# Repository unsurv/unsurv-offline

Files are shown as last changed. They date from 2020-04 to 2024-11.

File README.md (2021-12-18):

# unsurv-offline

Currently available on [crowdsupply](https://www.crowdsupply.com/unsurv-technologies/unsurv-offline)

This project is part of the unsurv framework to fight privacy invasive technologies in the offline world. unsurv-offline logs your encounters with surveillance cameras and creates a daily report for you via NFC to review in the unsurv-companion Android app.

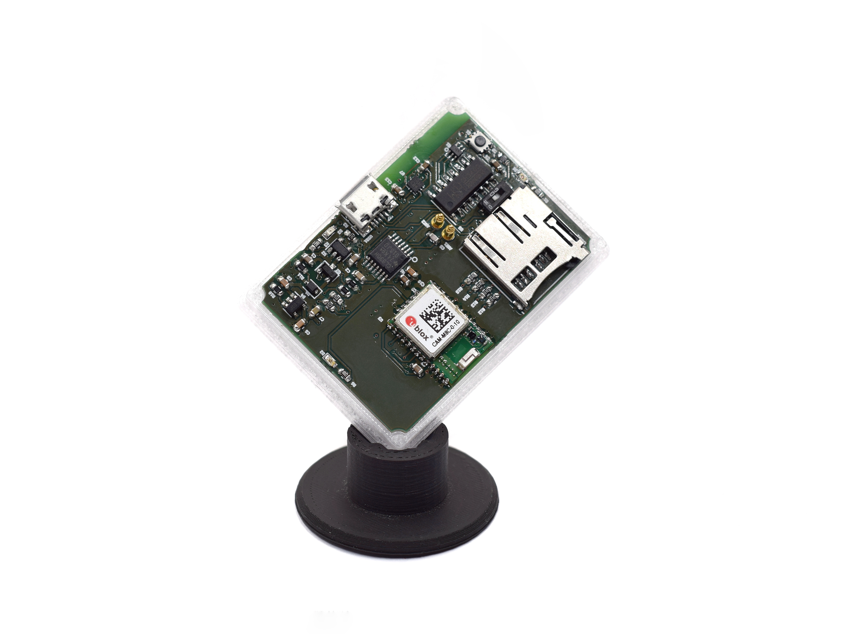
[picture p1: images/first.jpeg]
main PCB unsurv-offline


Demo: https://vimeo.com/497241039

This device can easily be adapted to different use cases via the Arduino IDE. Arduino library + board integration are planned.

List of features

- ESP32 D4
- ublox M8C GNSS receiver
- RF430CL330H NFC 
- BMA400 accelerometer
- SD card reader
- MCP73831 single cell LiPo charging
- CH340 USB to Serial

Software:
- [unsurv-offline](https://github.com/unsurv/unsurv-offline/tree/master/software/unsurv-offline)
- [other examples](https://github.com/unsurv/unsurv-offline/tree/master/software/examples) (tap to log location, location logging + step counting)

Hardware:
- [PCB design](https://github.com/unsurv/unsurv-offline/tree/master/unsurv_offline_pcb/main) (KiCad files)
- [case design](https://github.com/unsurv/unsurv-offline/tree/master/case) (FreeCAD + STL files)

Special thanks to:

- SparkFun for maintaining the [ublox library](https://github.com/sparkfun/SparkFun_Ublox_Arduino_Library)
- [awong1900](https://github.com/awong1900/RF430CL330H_Shield) for his work on the RF430
- [kriswiner](https://github.com/kriswiner/BMA400) for his BMA400 library

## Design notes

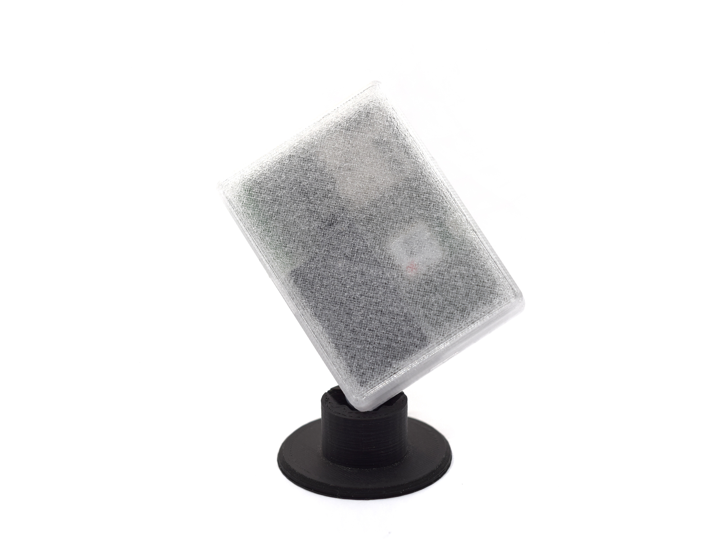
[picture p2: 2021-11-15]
images/third.jpeg

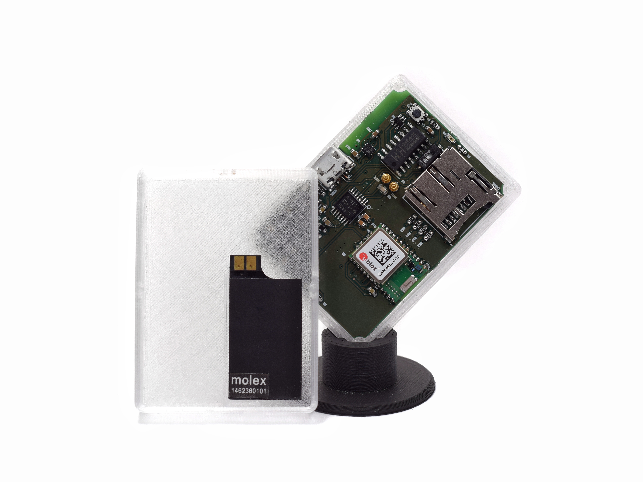
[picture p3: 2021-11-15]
images/pledge_kit.jpeg

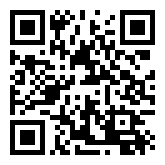
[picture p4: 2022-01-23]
images/GitHub_QR.png

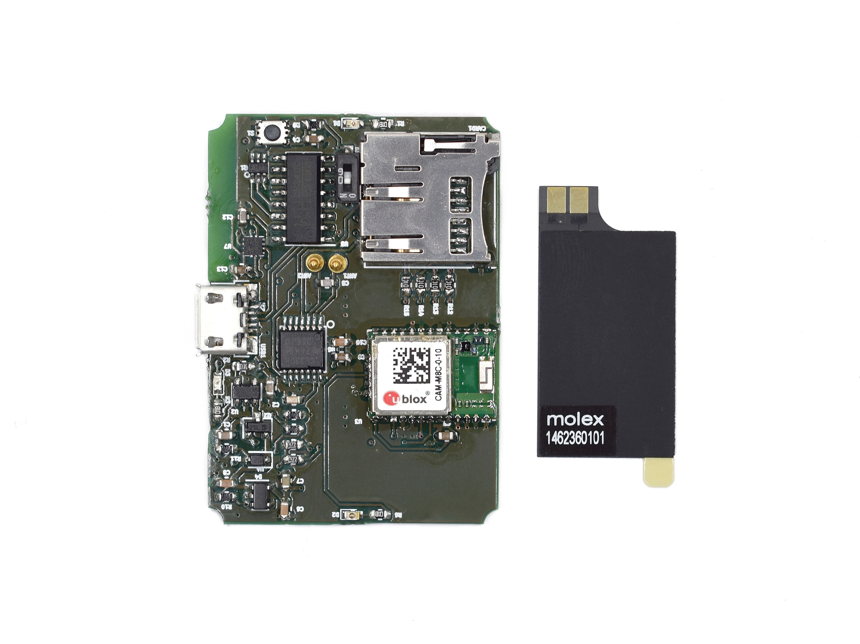
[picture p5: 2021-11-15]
images/pledge_pcb.jpeg

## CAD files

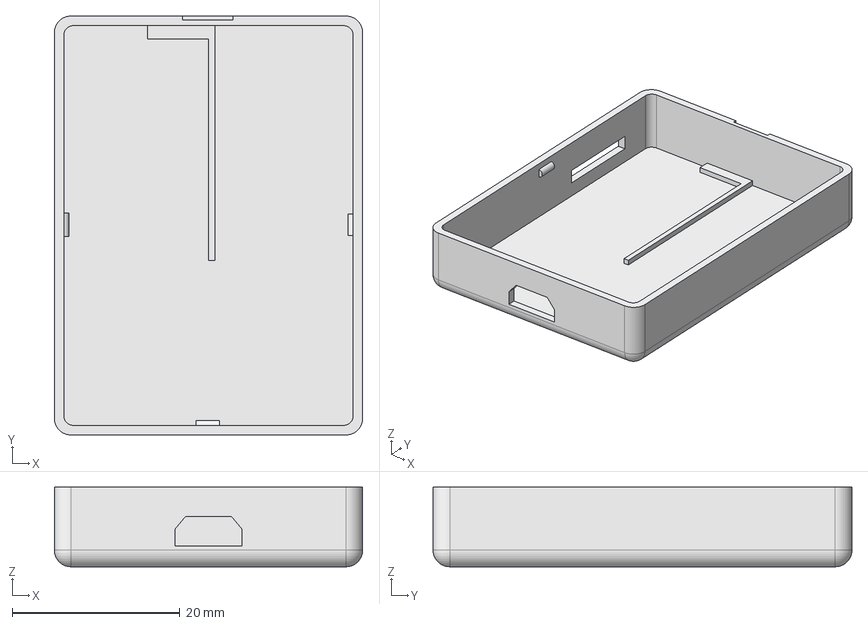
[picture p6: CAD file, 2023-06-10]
case/d4_case_top .FCStd
36.8 x 50.0 x 9.50 mm

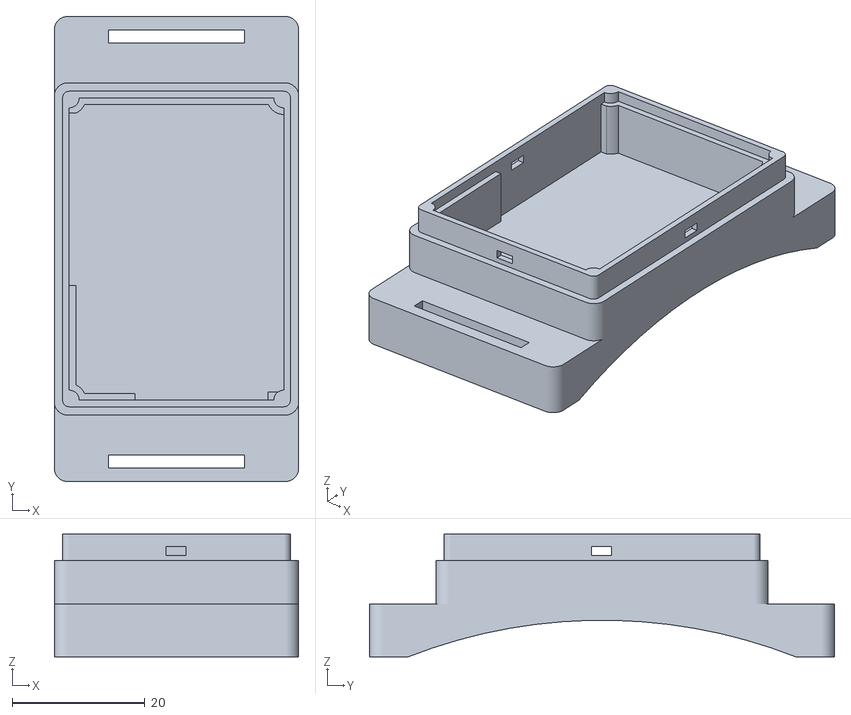
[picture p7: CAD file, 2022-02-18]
case/special/d4_case_bottom_collar_mount-Body.stl
36.8 x 70.0 x 18.5

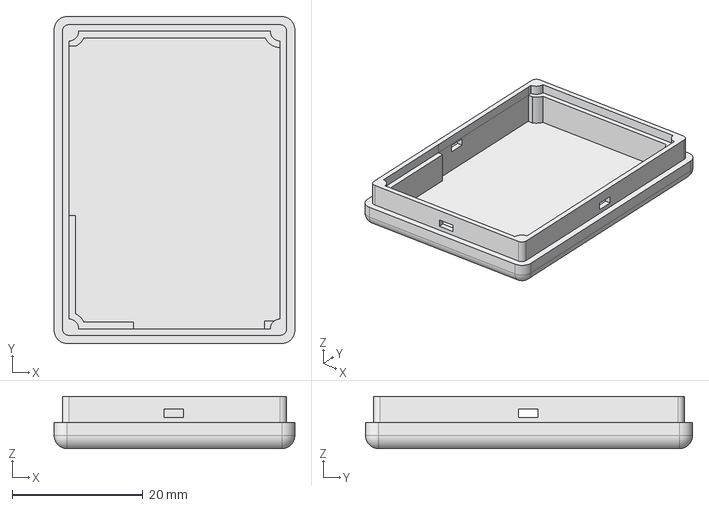
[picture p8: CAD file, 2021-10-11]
case/d4_case_bottom.FCStd
36.8 x 50.0 x 8.00 mm

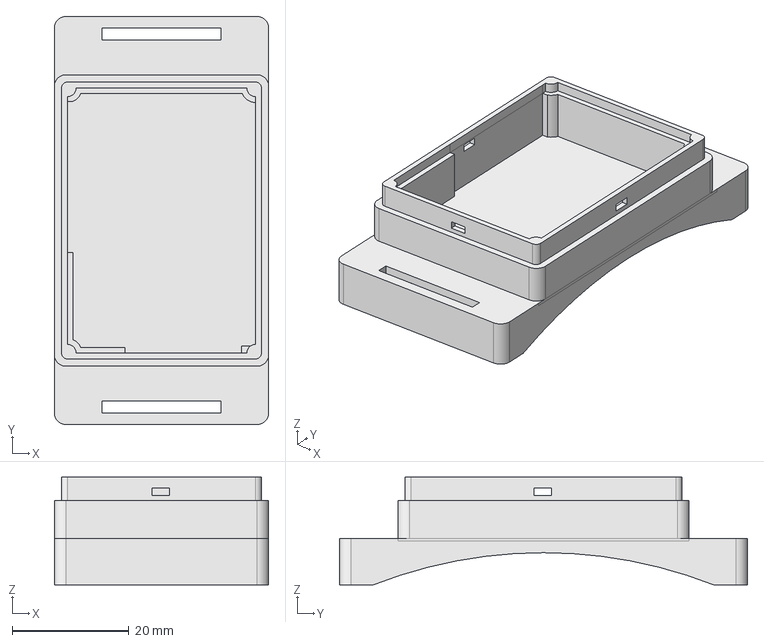
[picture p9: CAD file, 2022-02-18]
case/special/d4_case_bottom_collar_mount.FCStd
36.8 x 70.0 x 18.5 mm

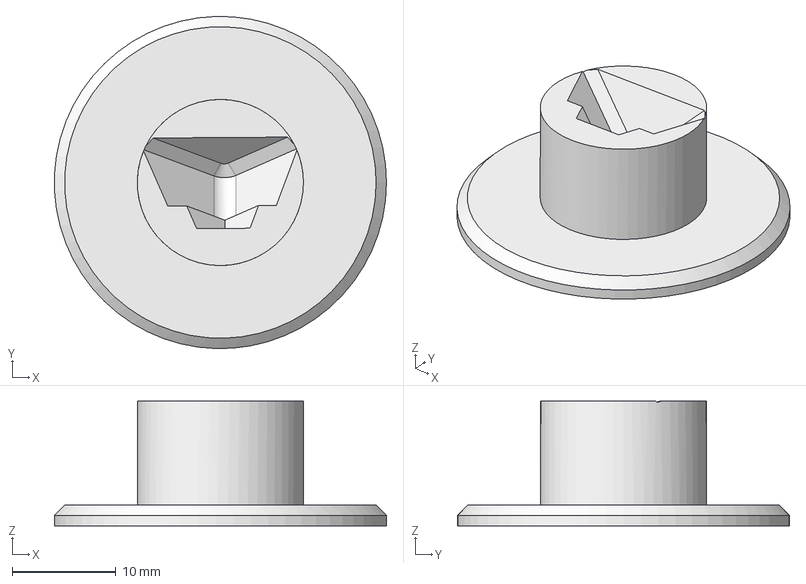
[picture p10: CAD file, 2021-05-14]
case/stand.FCStd
32.0 x 32.0 x 12.0 mm

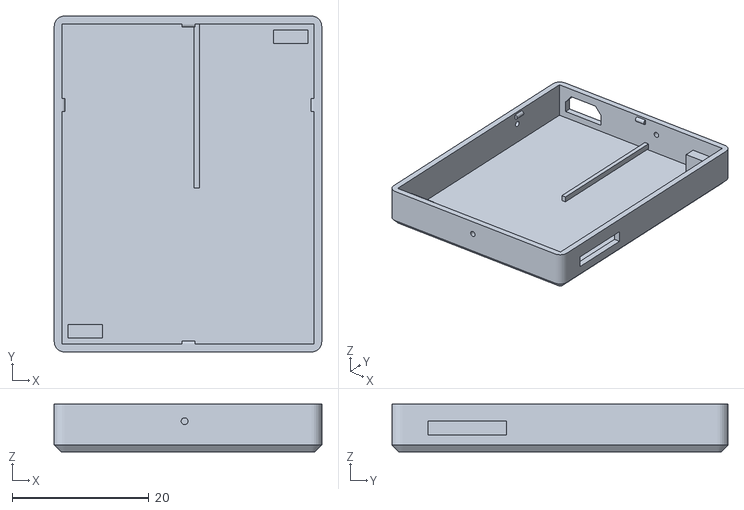
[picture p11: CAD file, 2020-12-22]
case/case_top.stl
39.1 x 49.1 x 7.00

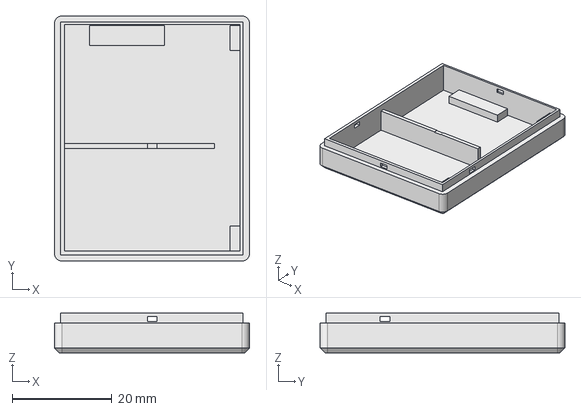
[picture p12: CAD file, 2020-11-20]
case/case_bottom.FCStd
39.1 x 49.1 x 8.00 mm

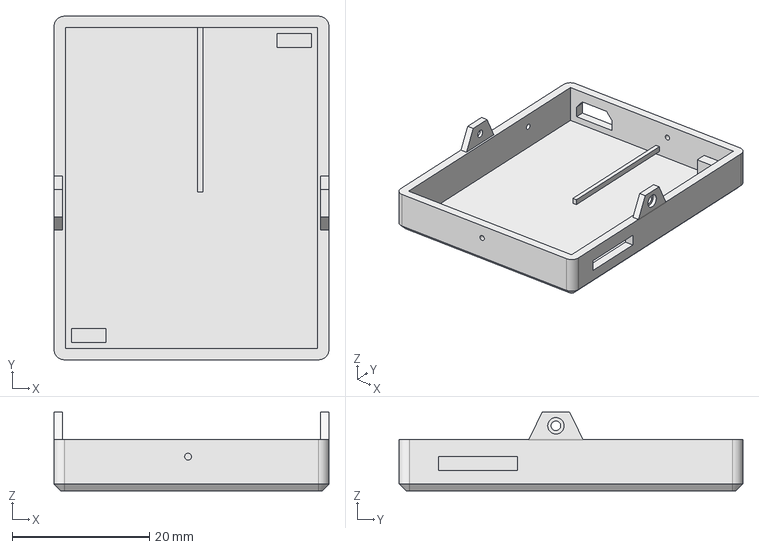
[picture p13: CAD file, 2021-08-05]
case/screw_case_top.FCStd
40.1 x 50.1 x 11.5 mm

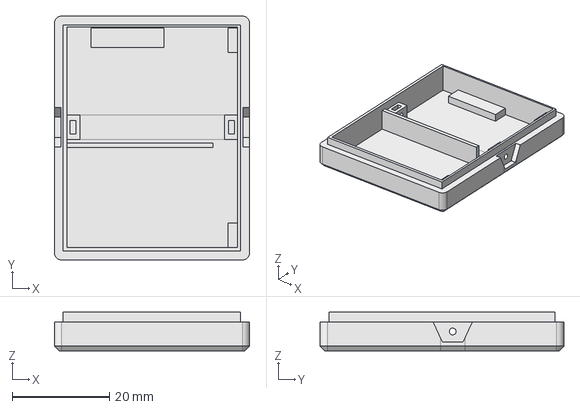
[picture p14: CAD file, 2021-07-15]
case/screw_case_bottom.FCStd
40.1 x 50.1 x 8.00 mm

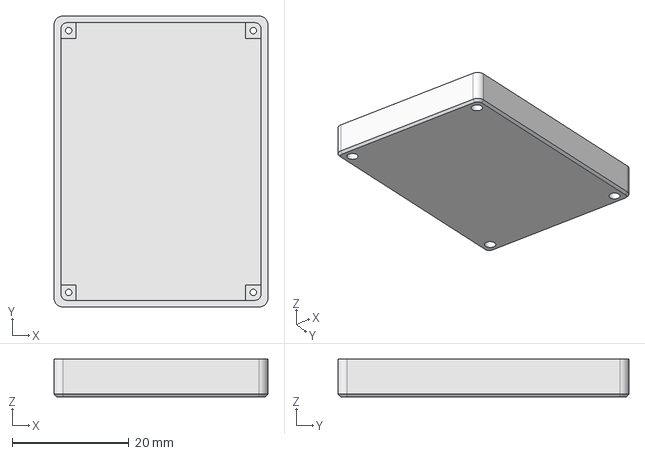
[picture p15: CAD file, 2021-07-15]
case/d4_screw_case_top.FCStd
36.6 x 49.8 x 6.50 mm

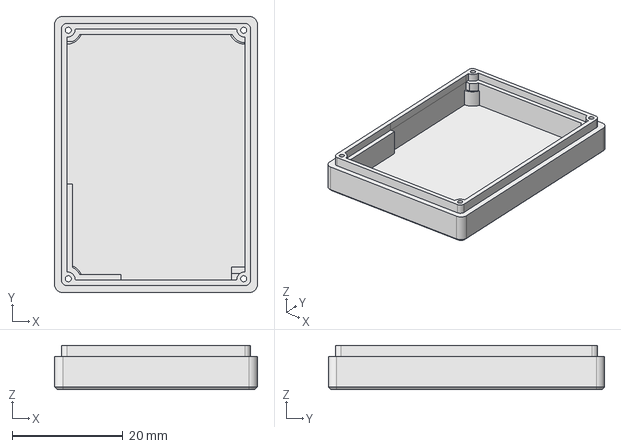
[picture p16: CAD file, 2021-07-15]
case/d4_screw_case_bottom.FCStd
36.6 x 49.8 x 8.00 mm

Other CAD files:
case/d4_case_bottom_test.FCStd
case/case_top_rebuild.FCStd
case/screw_case_botttom.stl
case/old designs/d4_case_bottom_test.FCStd
case/old designs/case_top_rebuild.FCStd
case/case_bottom.stl
case/d4_case_bottom.stl
case/d4_case_bottom_test.stl
case/d4_case_top.stl
case/d4_screw_case_bottom.stl
case/d4_screw_case_top.stl
case/old designs/case_bottom.stl
case/old designs/d4_case_bottom_test.stl
case/old designs/d4_screw_case_bottom.stl
case/old designs/d4_screw_case_top.stl
case/old designs/screw_case_botttom.stl
case/old designs/screw_case_top.stl
case/screw_case_top.stl
case/stand.stl

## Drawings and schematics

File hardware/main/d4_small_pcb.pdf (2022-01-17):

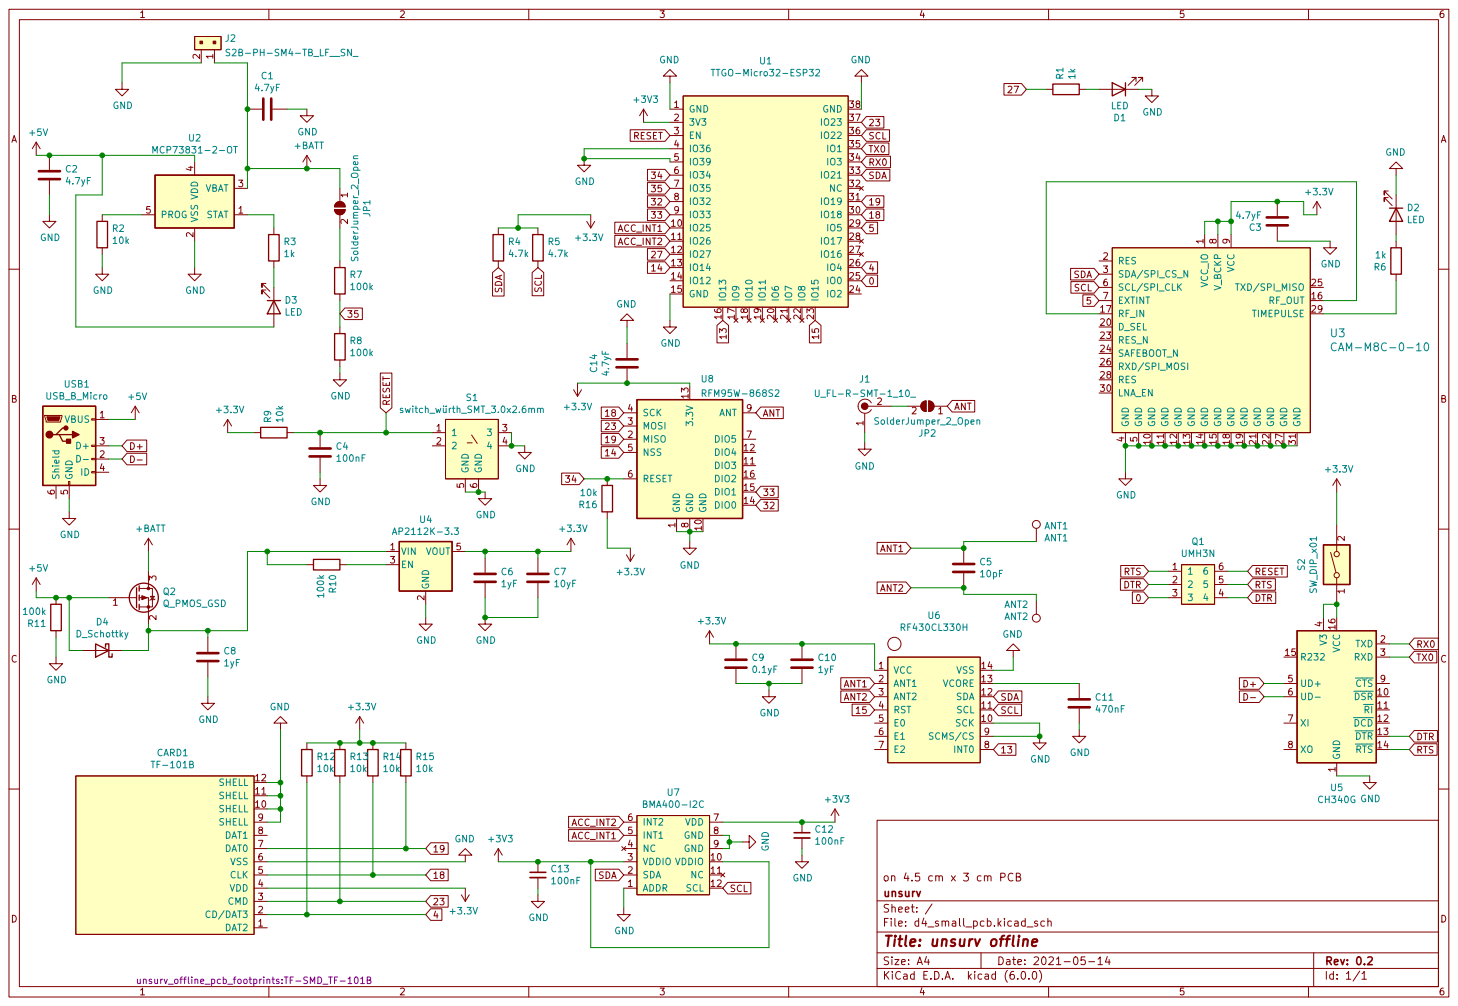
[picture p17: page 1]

1 GND 10 GND 11 GND 12 GND 13 GND 14 GND 15 RF_OUT 16 RF_IN 17 GND 18 GND 19 RES 2 D_SEL 20 GND 21 GND 22 RES_N 23 SAFEBOOT_N 24 TXD/SPI_MISO 25 RXD/SPI_MOSI 26 GND 27 RES 28 TIMEPULSE 29 SDA/SPI_CS_N 3

1 GND 10 DIO3 11 DIO4 12 3.3V 13 DIO0 14 DIO1 15 DIO2 16 MISO 2 MOSI 3 SCK 4 NSS 5 RESET 6 DIO5 7 GND

1 ~{DSR}10 ~{RI}11 ~{DCD}12 ~{DTR}13 ~{RTS}14 R232 15 VCC 16 TXD 2 RXD 3 V3

4 UD+ 5 UD- 6 XI 7 XO 8 ~{CTS} 9 U5 CH340G

on 4.5 cm x 3 cm PCB
File: d4_small_pcb.kicad_sch Sheet: / unsurv

Id: 1/1 Title: unsurv offline

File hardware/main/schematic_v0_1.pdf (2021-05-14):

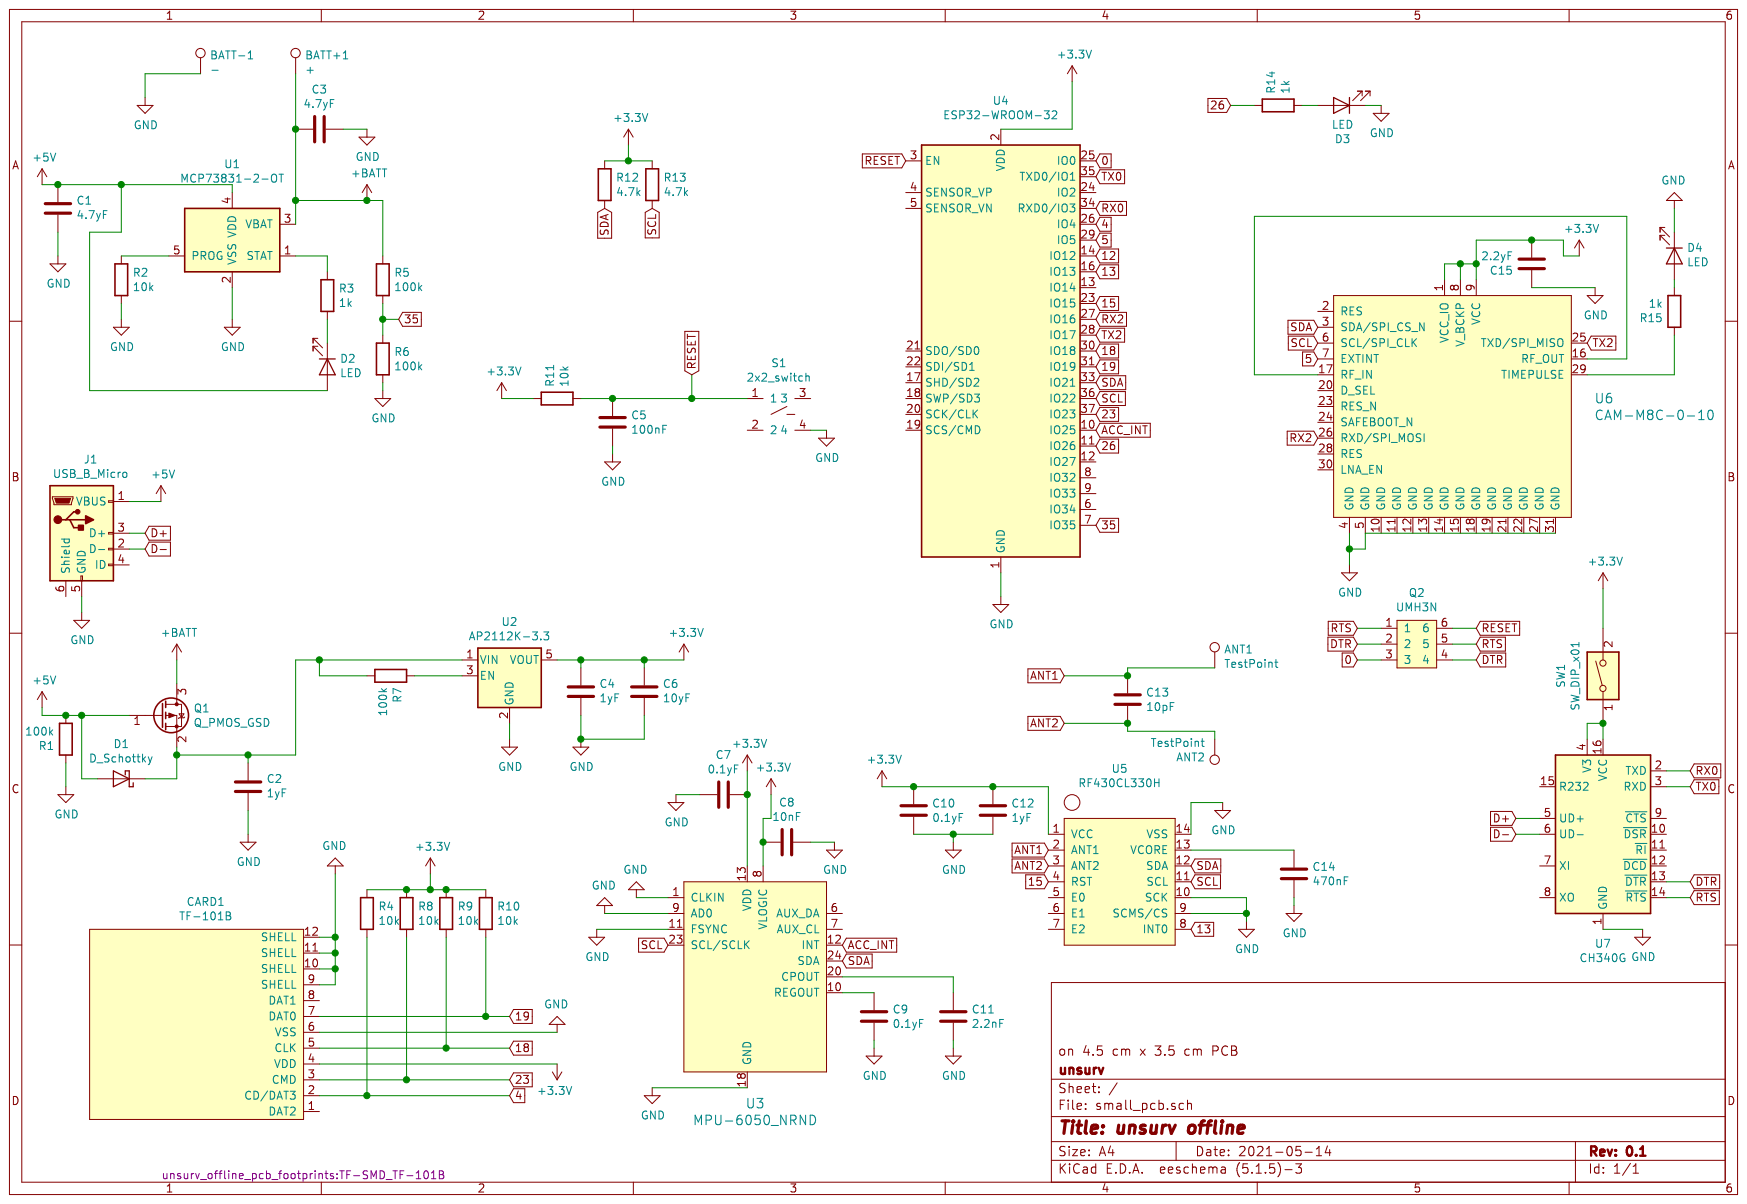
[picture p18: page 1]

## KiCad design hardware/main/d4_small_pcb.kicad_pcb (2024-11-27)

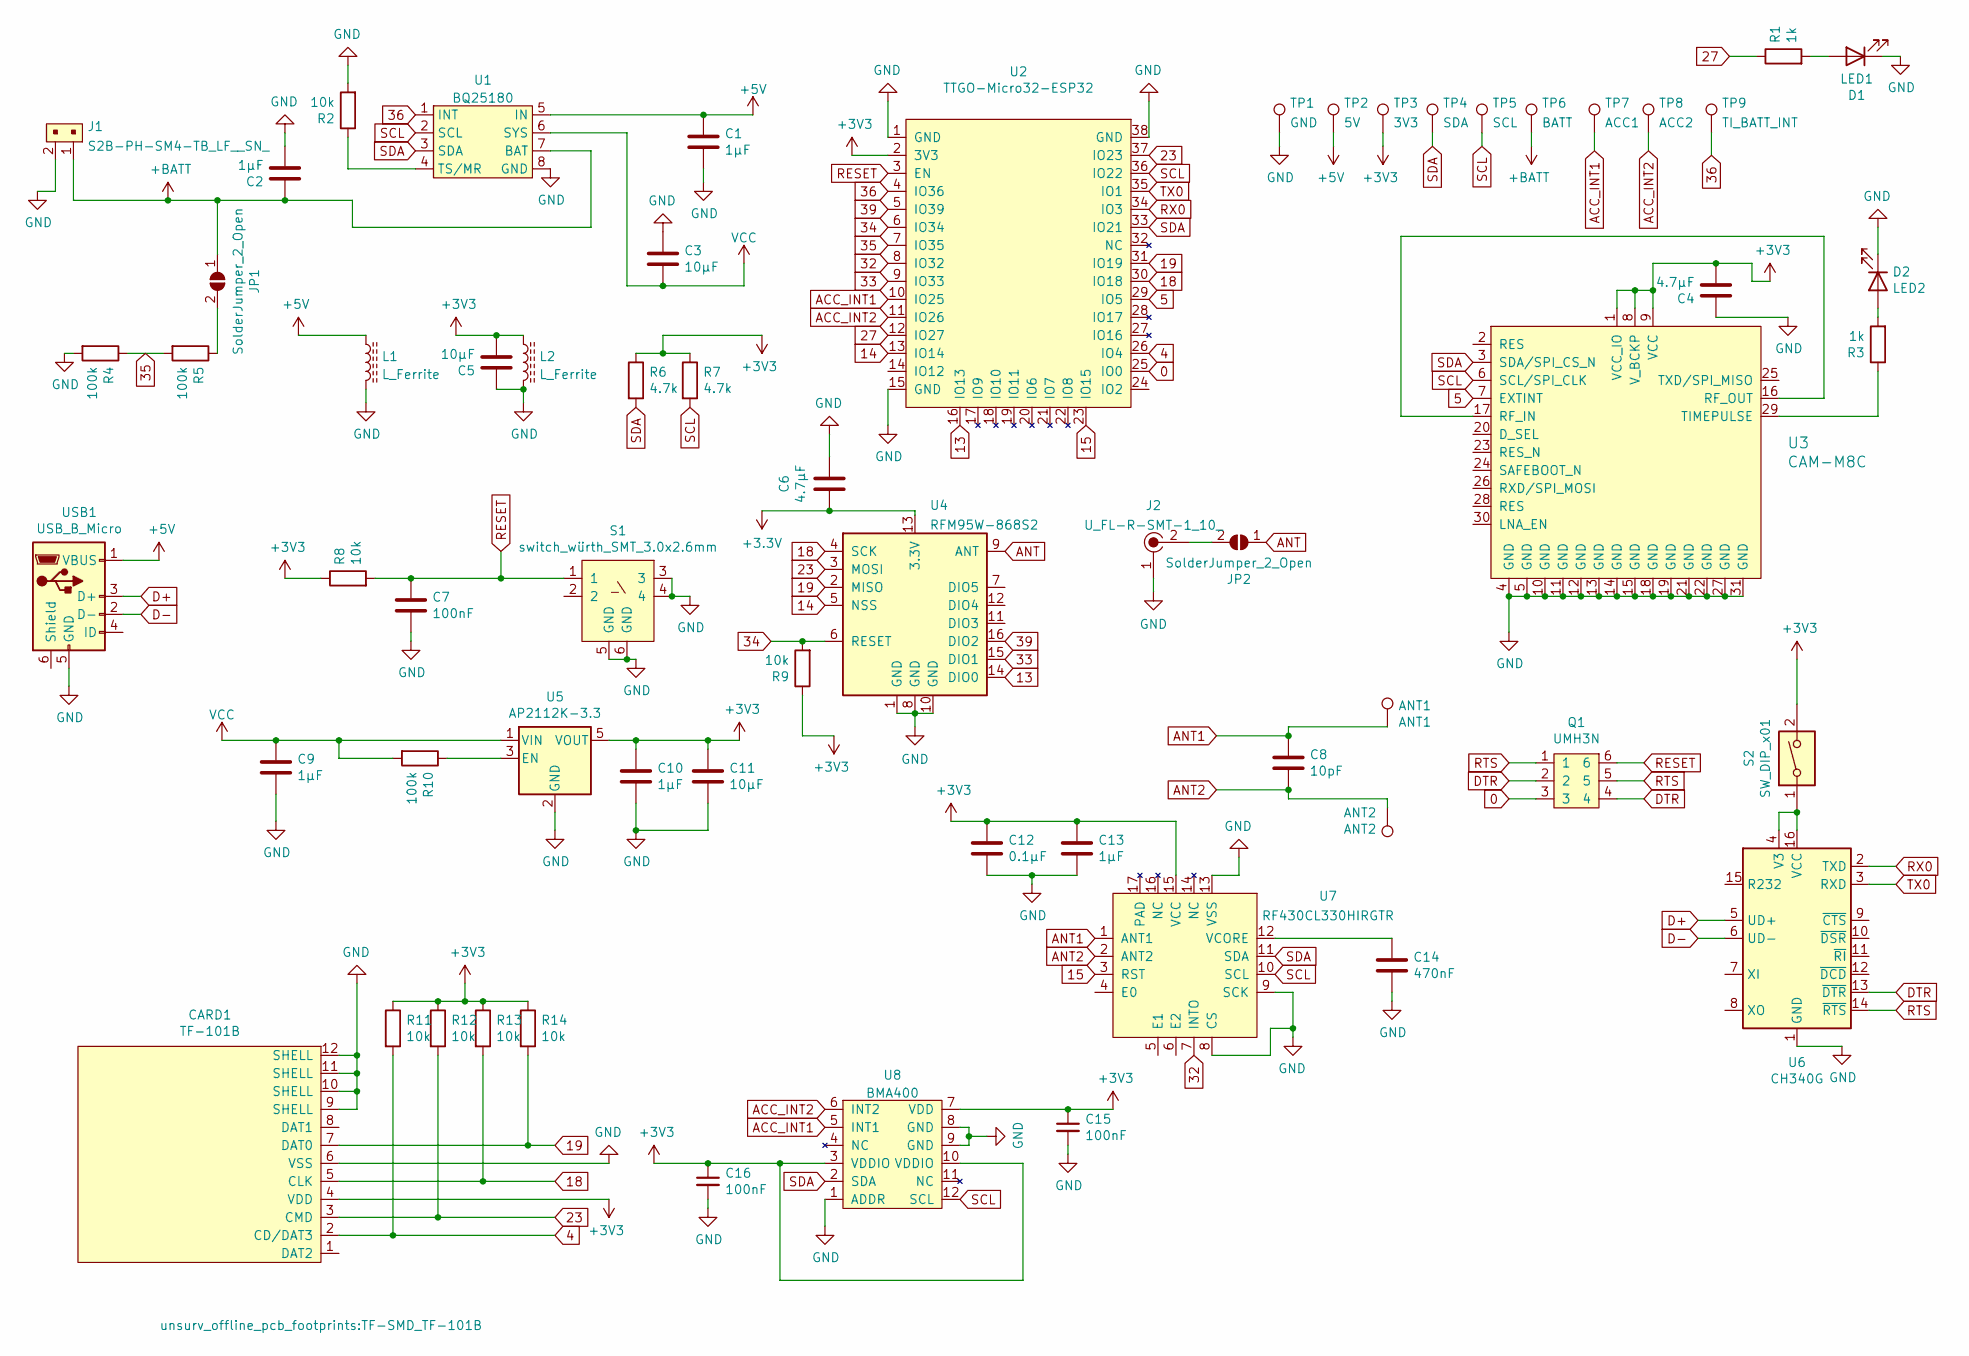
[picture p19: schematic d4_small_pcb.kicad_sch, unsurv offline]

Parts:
ANT1: ANT1; PogoPin_2_2mm_circular; MPN P70-1010045R
ANT2: ANT2; PogoPin_2_2mm_circular; MPN P70-1010045R
C1, C2, C9, C10, C13: 1µF; C_0603_1608Metric
C3, C5, C11: 10µF; C_0603_1608Metric
C4, C6: 4.7µF; C_0603_1608Metric
C7, C15, C16: 100nF; C_0603_1608Metric
C8: 10pF; C_0603_1608Metric
C12: 0.1µF; C_0603_1608Metric
C14: 470nF; C_0603_1608Metric
CARD1: TF-101B; TF-SMD_TF-101B; MPN TF-101B
D1: LED1; LED_0603
D2: LED2; LED_0603
J1: S2B-PH-SM4-TB_LF__SN_; PinHeader_2x1mm_P2mm_SMD_RA; MPN S2B-PH-SM4-TB(LF)(SN); Digi-Key_PN 455-1749-1-ND
J2: U_FL-R-SMT-1_10_; Coax_Conn_U.FL; MPN U.FL-R-SMT-1(10); Digi-Key_PN H11891CT-ND
JP1, JP2: SolderJumper_2_Open; SolderJumper-2_P1.3mm_Open_RoundedPad1.0x1.5mm
L1, L2: L_Ferrite; L_0603_1608Metric
Q1: UMH3N
R1, R3: 1k; R_0603_1608Metric
R2, R8, R9, R11, R12, R13, R14: 10k; R_0603_1608Metric
R4, R5, R10: 100k; R_0603_1608Metric
R6, R7: 4.7k; R_0603_1608Metric
S1: switch_würth_SMT_3.0x2.6mm; würth_SMT_3.0x2.6mm; MPN 435171014816
S2: SW_DIP_x01; CHS-01TA; MPN CHS-01TA
TP1: GND; TestPoint_Pad_D1.0mm
TP2: 5V; TestPoint_Pad_D1.0mm
TP3: 3V3; TestPoint_Pad_D1.0mm
TP4: SDA; TestPoint_Pad_D1.0mm
TP5: SCL; TestPoint_Pad_D1.0mm
TP6: BATT; TestPoint_Pad_D1.0mm
TP7: ACC1; TestPoint_Pad_D1.0mm
TP8: ACC2; TestPoint_Pad_D1.0mm
TP9: TI_BATT_INT; TestPoint_Pad_D1.0mm
U1: BQ25180; MPN BQ25180YBGR
U2: TTGO-Micro32-ESP32
U3: CAM-M8C; GPS_Module_CAM-M8C-0; MPN CAM-M8C-0-10; Digi-Key_PN 672-CAM-M8C-0-10CT-ND
U4: RFM95W-868S2; HOPERF_RFM9XW_SMD
U5: AP2112K-3.3; SOT-23-5
U6: CH340G; SOIC-16_3.9x9.9mm_P1.27mm
U7: RF430CL330HIRGTR‎; RF430_3x3mm_regular; MPN RF430CL330HIRGTR
U8: BMA400; BMA400_regular
USB1: USB_B_Micro; USB_Micro-B_Amphenol_10103594-0001LF_Horizontal; MPN 10103594-0001LF

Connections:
0: Q1.3, U2.25 (IO0)
4: CARD1.2 (CD/DAT3), R11.2, U2.26 (IO4)
5: U2.29 (IO5), U3.7 (EXTINT)
13: U2.16 (IO13), U4.14 (DIO0)
14: U2.13 (IO14), U4.5 (NSS)
15: U2.23 (IO15), U7.3 (RST)
18: CARD1.5 (CLK), R13.2, U2.30 (IO18), U4.4 (SCK)
19: CARD1.7 (DAT0), R14.2, U2.31 (IO19), U4.2 (MISO)
23: CARD1.3 (CMD), R12.2, U2.37 (IO23), U4.3 (MOSI)
27: R1.1, U2.12 (IO27)
32: U2.8 (IO32), U7.7 (INTO)
33: U2.9 (IO33), U4.15 (DIO1)
34: R9.2, U2.6 (IO34), U4.6 (RESET)
35: R4.1, R5.2, U2.7 (IO35)
36: TP9.1, U1.1 (INT), U2.4 (IO36)
39: U2.5 (IO39), U4.16 (DIO2)
+3.3V: C6.2, U4.13 (3.3V)
+3V3: C4.2, C5.1, C10.2, C11.2, C12.1, C13.1, C15.1, C16.1, CARD1.4 (VDD), L2.1, R6.1, R7.1, R8.1, R9.1, R11.1, R12.1, R13.1, R14.1, S2.2, TP3.1, U2.2 (3V3), U3.1 (VCC_IO), U3.8 (V_BCKP), U3.9 (VCC), U5.5 (VOUT), U7.15 (VCC), U8.3 (VDDIO), U8.7 (VDD), U8.10 (VDDIO)
+5V: C1.2, L1.1, TP2.1, U1.5 (IN), USB1.1 (VBUS)
+BATT: C2.2, J1.1, JP1.1 (A), TP6.1, U1.7 (BAT)
ACC_INT1: TP7.1, U2.10 (IO25), U8.5 (INT1)
ACC_INT2: TP8.1, U2.11 (IO26), U8.6 (INT2)
ANT: JP2.1 (A), U4.9 (ANT)
ANT1: ANT1.1, C8.1, U7.1 (ANT1)
ANT2: ANT2.1, C8.2, U7.2 (ANT2)
D+: U6.5 (UD+), USB1.3 (D+)
D-: U6.6 (UD-), USB1.2 (D-)
DTR: Q1.2, Q1.4, U6.13 (~DTR)
GND: C1.1, C2.1, C3.2, C4.1, C5.2, C6.1, C7.2, C9.1, C10.1, C11.1, C12.2, C13.2, C14.2, C15.2, C16.2, CARD1.6 (VSS), CARD1.9 (SHELL), CARD1.10 (SHELL), CARD1.11 (SHELL), CARD1.12 (SHELL), D1.1 (K), D2.1 (K), J1.2, J2.1, L1.2, L2.2, R2.2, R4.2, S1.3, S1.4, S1.5 (GND), S1.6 (GND), TP1.1, U1.8 (GND), U2.1 (GND), U2.15 (GND), U2.38 (GND), U3.4 (GND), U3.5 (GND), U3.10 (GND), U3.11 (GND), U3.12 (GND), U3.13 (GND), U3.14 (GND), U3.15 (GND), U3.18 (GND), U3.19 (GND), U3.21 (GND), U3.22 (GND), U3.27 (GND), U3.31 (GND), U4.1 (GND), U4.8 (GND), U4.10 (GND), U5.2 (GND), U6.1 (GND), U7.8 (CS), U7.9 (SCK), U7.13 (VSS), U8.1 (ADDR), U8.8 (GND), U8.9 (GND), USB1.5 (GND)
unnamed: D1.2 (A), R1.2
unnamed: D2.2 (A), R3.2
unnamed: JP1.2 (B), R5.1
unnamed: J2.2, JP2.2 (B)
unnamed: R2.1, U1.4 (TS/MR)
unnamed: U3.16 (RF_OUT), U3.17 (RF_IN)
unnamed: R3.1, U3.29 (TIMEPULSE)
unnamed: R10.1, U5.3 (EN)
unnamed: S2.1, U6.4 (V3), U6.16 (VCC)
unnamed: C14.1, U7.12 (VCORE)
RESET: C7.1, Q1.6, R8.2, S1.1, U2.3 (EN)
RTS: Q1.1, Q1.5, U6.14 (~RTS)
RX0: U2.34 (IO3), U6.2 (TXD)
SCL: R7.2, TP5.1, U1.2 (SCL), U2.36 (IO22), U3.6 (SCL/SPI_CLK), U7.10 (SCL), U8.12 (SCL)
SDA: R6.2, TP4.1, U1.3 (SDA), U2.33 (IO21), U3.3 (SDA/SPI_CS_N), U7.11 (SDA), U8.2 (SDA)
TX0: U2.35 (IO1), U6.3 (RXD)
VCC: C3.1, C9.2, R10.2, U1.6 (SYS), U5.1 (VIN)

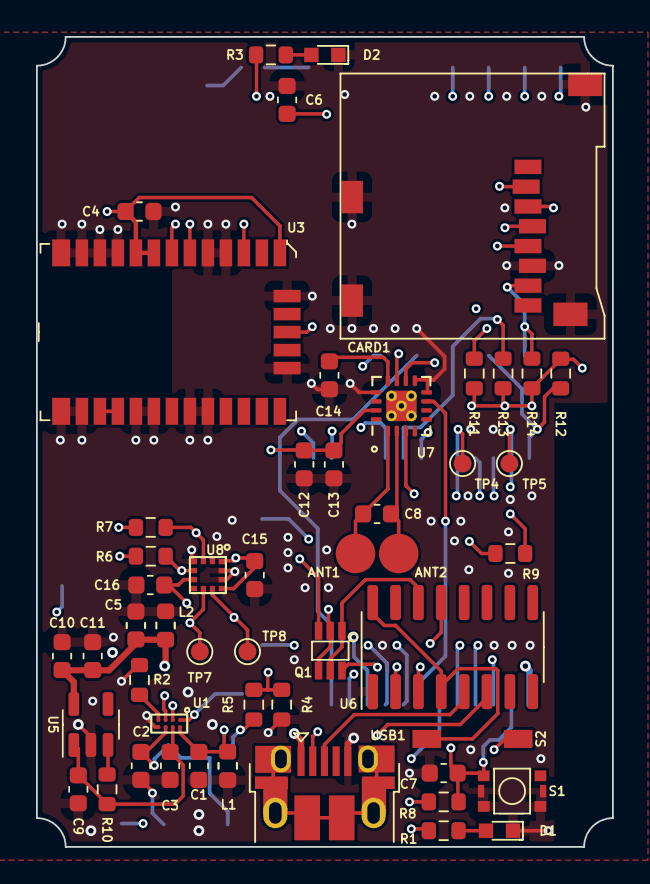
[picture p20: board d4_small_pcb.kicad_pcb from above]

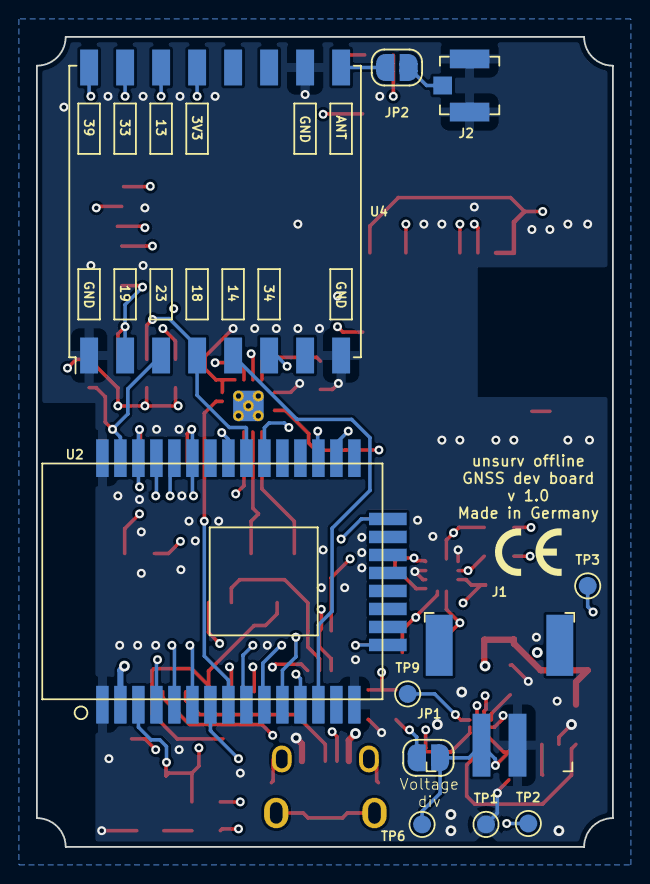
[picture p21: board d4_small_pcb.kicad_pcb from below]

Board: 4 copper layers, 32.0 x 45.0 mm, 62 parts (11 on the bottom side), 46 nets.

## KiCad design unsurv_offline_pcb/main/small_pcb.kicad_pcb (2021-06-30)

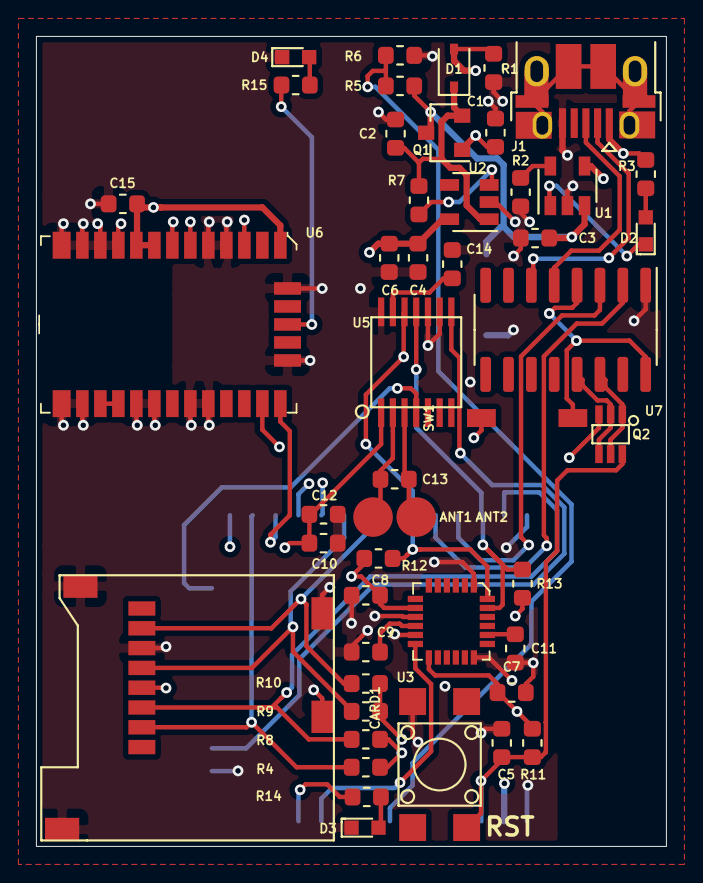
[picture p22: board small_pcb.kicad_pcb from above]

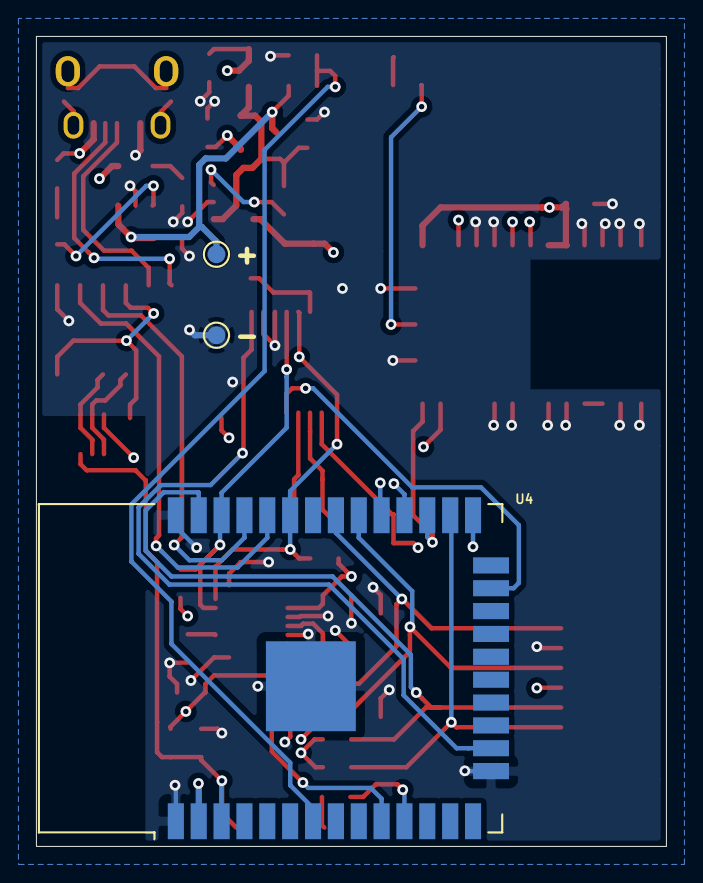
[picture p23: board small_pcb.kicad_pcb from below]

Board: 4 copper layers, 35.0 x 45.0 mm, 51 parts (3 on the bottom side), 41 nets.

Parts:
+: +; TestPoint_Pad_D1.0mm
-: -; TestPoint_Pad_D1.0mm
ANT1, ANT2: TestPoint; PogoPin_2_2mm_circular
C1, C3: 4.7yF; C_0603_1608Metric
C2, C4, C12: 1yF; C_0603_1608Metric
C5: 100nF; C_0603_1608Metric
C6: 10yF; C_0603_1608Metric
C7, C9, C10: 0.1yF; C_0603_1608Metric
C8: 10nF; C_0603_1608Metric
C11: 2.2nF; C_0603_1608Metric
C13: 10pF; C_0603_1608Metric
C14: 470nF; C_0603_1608Metric
C15: 2.2yF; C_0603_1608Metric
CARD1: TF-101B; TF-SMD_TF-101B
D1: D_Schottky; D_SOD-323
D2, D3, D4: LED; LED_0603
J1: USB_B_Micro; USB_Micro-B_Amphenol_10103594-0001LF_Horizontal
Q1: Q_PMOS_GSD; SOT-23
Q2: UMH3N
R1, R2, R4, R8, R9, R10, R11: 10k; R_0603_1608Metric
R3, R14, R15: 1k; R_0603_1608Metric
R5, R6, R7: 100k; R_0603_1608Metric
R12, R13: 4.7k; R_0603_1608Metric
RST: 2x2_switch; 2x2 Switch
SW1: SW_DIP_x01; CHS-01TA
U1: MCP73831-2-OT; SOT-23-5
U2: AP2112K-3.3; SOT-23-5
U3: MPU-6050_NRND; QFN-24-1EP_4x4mm
U4: ESP32-WROOM-32
U5: RF430CL330H
U6: CAM-M8C-0-10; GPS_Module_CAM-M8C-0
U7: CH340G; SOIC-16_3.9x9.9mm_P1.27mm

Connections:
0: Q2.3, U4.25
4: CARD1.2, R4.2, U4.26
5: U4.29, U6.7
13: U4.16, U5.8
15: U4.23, U5.4
18: CARD1.5, R9.2, U4.30
19: CARD1.7, R10.2, U4.31
23: CARD1.3, R8.2, U4.37
26: R14.1, U4.11
35: R5.2, R6.1, U4.7
+3V3: C4.2, C6.2, C7.1, C8.2, C10.1, C12.1, C15.2, CARD1.4, R4.1, R8.1, R9.1, R10.1, R11.1, R12.1, R13.1, SW1.2, U2.5, U3.8, U3.13, U4.2, U5.1, U6.1, U6.8, U6.9
+5V: C1.2, D1.2, J1.1, Q1.1, R1.2, R3.2, U1.4
+BATT: +.1, C3.2, Q1.3, R5.1, U1.3
ACC_INT: U3.12, U4.10
ANT1: ANT1.1, C13.1, U5.2
ANT2: ANT2.1, C13.2, U5.3
D+: J1.3, U7.5
D-: J1.2, U7.6
DTR: Q2.2, Q2.4, U7.13
GND: -.1, C1.1, C2.1, C3.1, C4.1, C5.2, C6.1, C7.2, C8.1, C9.2, C10.2, C11.2, C12.2, C14.2, C15.1, CARD1.6, CARD1.9, CARD1.10, CARD1.11, CARD1.12, D3.1, D4.1, J1.5, R1.1, R2.2, R6.2, RST.4, U1.2, U2.2, U3.1, U3.9, U3.11, U3.18, U4.1, U4.15, U4.38, U4.39, U5.9, U5.10, U5.14, U6.4, U6.5, U6.10, U6.11, U6.12, U6.13, U6.14, U6.15, U6.18, U6.19, U6.21, U6.22, U6.27, U6.31, U7.1
unnamed: C2.2, D1.1, Q1.2, R7.2, U2.1
unnamed: C9.1, U3.10
unnamed: C11.1, U3.20
unnamed: C14.1, U5.13
unnamed: D2.1, U1.1
unnamed: D2.2, R3.1
unnamed: D3.2, R14.2
unnamed: D4.2, R15.2
unnamed: R2.1, U1.5
unnamed: R7.1, U2.3
unnamed: R15.1, U6.29
unnamed: SW1.1, U7.4, U7.16
unnamed: U6.16, U6.17
RESET: C5.1, Q2.6, R11.2, RST.1, U4.3
RTS: Q2.1, Q2.5, U7.14
RX0: U4.34, U7.2
RX2: U4.27, U6.26
SCL: R13.2, U3.23, U4.36, U5.11, U6.6
SDA: R12.2, U3.24, U4.33, U5.12, U6.3
TX0: U4.35, U7.3
TX2: U4.28, U6.25

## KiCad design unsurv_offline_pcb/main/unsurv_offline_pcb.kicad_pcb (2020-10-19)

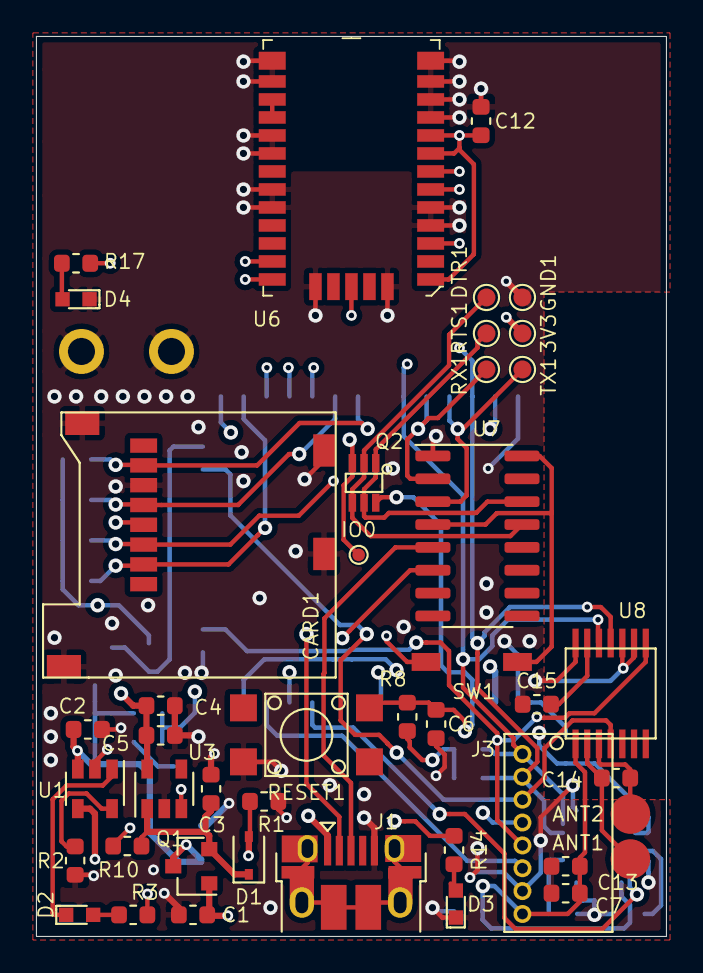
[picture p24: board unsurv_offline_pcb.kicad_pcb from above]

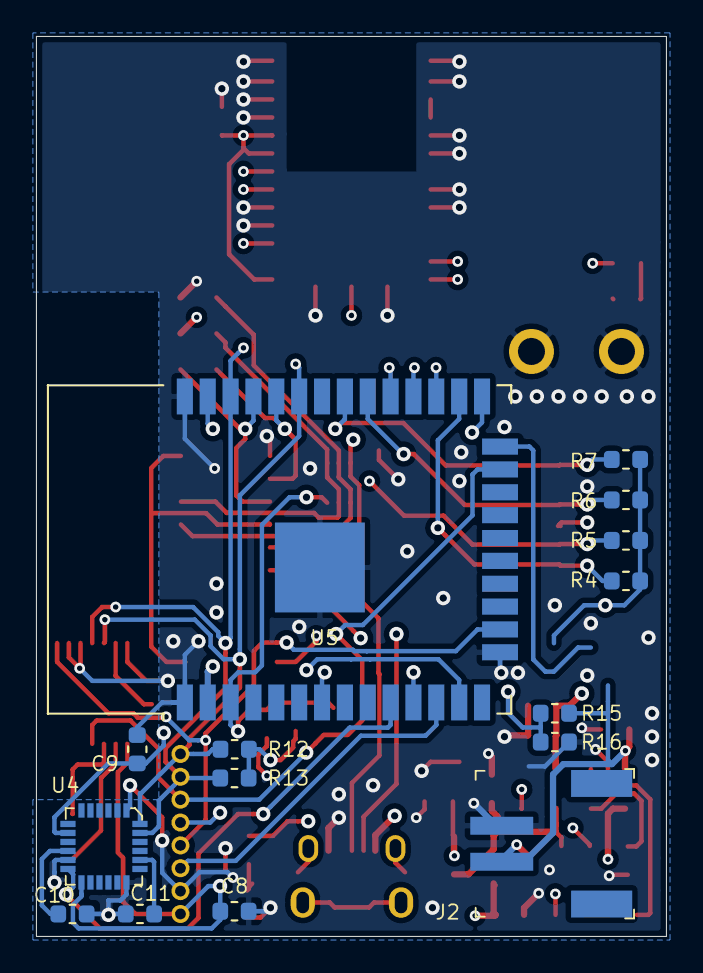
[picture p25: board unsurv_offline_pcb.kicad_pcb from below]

Board: 4 copper layers, 35.0 x 50.0 mm, 60 parts (15 on the bottom side), 43 nets.

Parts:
3V3: TestPoint; TestPoint_Pad_D1.0mm
ANT1, ANT2: TestPoint; PogoPin_2_2mm_circular
C1, C2: 4.7yF; C_0603_1608Metric
C3, C4, C13: 1yF; C_0603_1608Metric
C5: 10yF; C_0603_1608Metric
C6: 100nF; C_0603_1608Metric
C7, C8, C10: 0.1yF; C_0603_1608Metric
C9: 10nF; C_0603_1608Metric
C11: 2.2nF; C_0603_1608Metric
C12: 2.2yF; C_0603_1608Metric
C14: 10pF; C_0603_1608Metric
C15: 470nF; C_0603_1608Metric
CARD1: TF-101B; TF-SMD_TF-101B
D1: D_Schottky; D_SOD-323
D2, D3, D4: LED; LED_0603
DTR1: TestPoint; TestPoint_Pad_D1.0mm
GND1: TestPoint; TestPoint_Pad_D1.0mm
H1, H2: MountingHole_Pad; MountingHole_1.5mm_hole_in_FPaste
IO0: TestPoint; TestPoint_Pad_D0.7mm
J1: USB_B_Micro; USB_Micro-B_Amphenol_10103594-0001LF_Horizontal
J2: S2B-PH-SM4-TB_LF__SN_; PinHeader_2x1mm_P2mm_SMD_RA
J3: 1.27mm_female_connector; LPPB081NGCN-RC
Q1: Q_PMOS_GSD; SOT-23
Q2: UMH3N
R1, R4, R5, R6, R7, R8: 10k; R_0603_1608Metric
R2: 2k; R_0603_1608Metric
R3, R14, R17: 1k; R_0603_1608Metric
R10, R15, R16: 100k; R_0603_1608Metric
R12, R13: 4.7k; R_0603_1608Metric
RESET1: 2x2_switch; 2x2 Switch
RTS1: TestPoint; TestPoint_Pad_D1.0mm
RX1: TestPoint; TestPoint_Pad_D1.0mm
SW1: SW_DIP_x01; CHS-01TA
TX1: TestPoint; TestPoint_Pad_D1.0mm
U1: MCP73831-2-OT; SOT-23-5
U3: AP2112K-3.3; SOT-23-5
U4: MPU-6050_NRND; QFN-24-1EP_4x4mm
U5: ESP32-WROOM-32
U6: CAM-M8C-0-10; GPS_Module_CAM-M8C-0
U7: CH340G; SOIC-16_3.9x9.9mm_P1.27mm
U8: RF430CL330H

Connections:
0: IO0.1, Q2.3, U5.25
4: CARD1.2, R4.2, U5.26
5: U5.29, U6.7
13: J3.4, U5.16, U8.8
14: J3.5, U5.13
15: J3.6, U5.23, U8.4
18: CARD1.5, R6.2, U5.30
19: CARD1.7, R7.2, U5.31
23: CARD1.3, R5.2, U5.37
26: R14.1, U5.11
27: J3.3, U5.12
35: R15.2, R16.1, U5.7
+3V3: 3V3.1, C4.2, C5.2, C7.1, C8.1, C9.2, C12.2, C13.1, CARD1.4, J3.1, R4.1, R5.1, R6.1, R7.1, R8.1, R12.1, R13.1, SW1.2, U3.5, U4.8, U4.13, U5.2, U6.1, U6.8, U6.9, U8.1
+5V: C1.2, D1.2, J1.1, Q1.1, R1.2, R3.2, U1.4
+BATT: C2.2, J2.2, Q1.3, R15.1, U1.3
ACC_INT: U4.12, U5.10
ANT1: ANT1.1, C14.1, U8.2
ANT2: ANT2.1, C14.2, U8.3
D+: J1.3, U7.5
D-: J1.2, U7.6
DTR: DTR1.1, Q2.2, Q2.4, U7.13
GND: C1.1, C2.1, C3.1, C4.1, C5.1, C6.2, C7.2, C8.2, C9.1, C10.2, C11.2, C12.1, C13.2, C15.2, CARD1.6, CARD1.9, CARD1.10, CARD1.11, CARD1.12, D3.1, D4.1, GND1.1, H1.1, H2.1, J1.5, J2.1, J3.2, R1.1, R2.2, R16.2, RESET1.4, U1.2, U3.2, U4.1, U4.11, U4.18, U5.1, U5.15, U5.38, U5.39, U6.4, U6.5, U6.10, U6.11, U6.12, U6.13, U6.14, U6.15, U6.18, U6.19, U6.21, U6.22, U6.27, U6.31, U7.1, U8.9, U8.10, U8.14
unnamed: C3.2, D1.1, Q1.2, R10.2, U3.1
unnamed: C10.1, U4.10
unnamed: C11.1, U4.20
unnamed: C15.1, U8.13
unnamed: D2.1, U1.1
unnamed: D2.2, R3.1
unnamed: D3.2, R14.2
unnamed: D4.2, R17.2
unnamed: R2.1, U1.5
unnamed: R10.1, U3.3
unnamed: R17.1, U6.29
unnamed: SW1.1, U7.4, U7.16
unnamed: U6.16, U6.17
RESET: C6.1, Q2.6, R8.2, RESET1.1, U5.3
RTS: Q2.1, Q2.5, RTS1.1, U7.14
RX0: RX1.1, U5.34, U7.2
RX2: U5.27, U6.26
SCL: J3.7, R13.2, U4.23, U5.36, U6.6, U8.11
SDA: J3.8, R12.2, U4.24, U5.33, U6.3, U8.12
TX0: TX1.1, U5.35, U7.3
TX2: U5.28, U6.25

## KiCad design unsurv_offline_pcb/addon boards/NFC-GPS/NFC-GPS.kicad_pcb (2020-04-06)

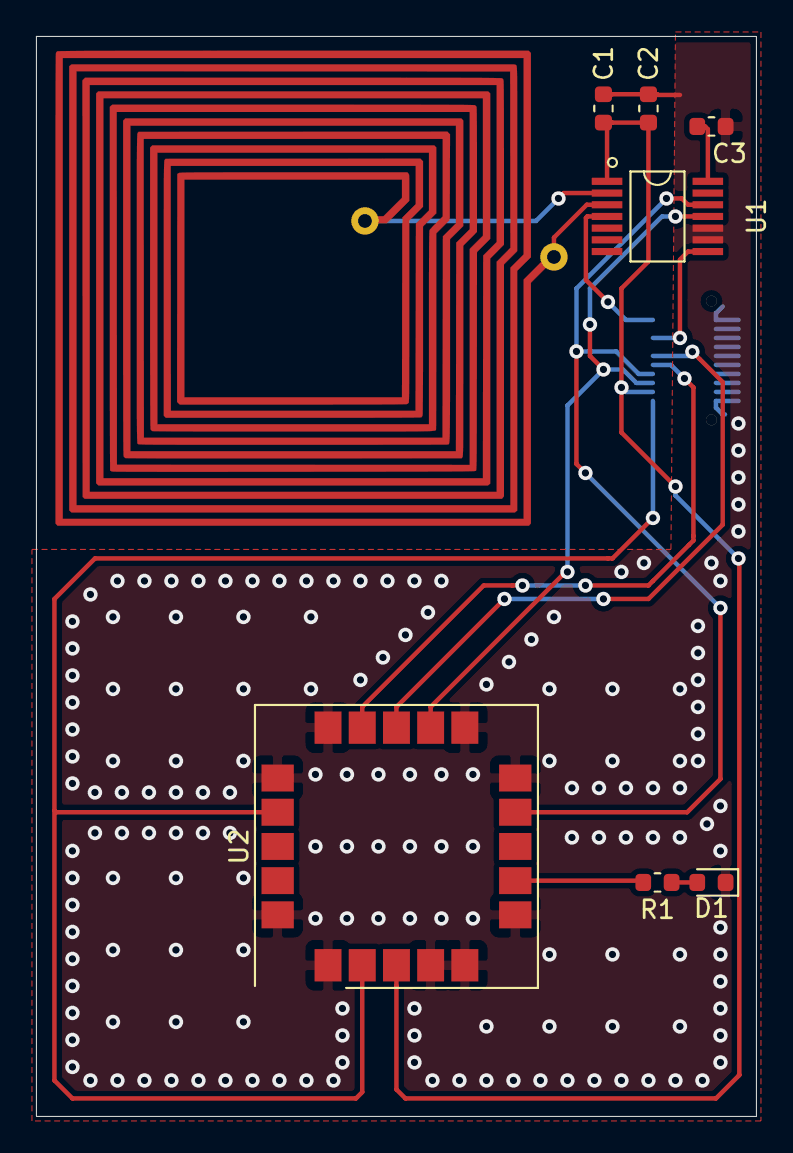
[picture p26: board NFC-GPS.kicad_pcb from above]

Board: 2 copper layers, 40.0 x 60.0 mm, 9 parts (1 on the bottom side), 14 nets.

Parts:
AE1: NfcAntenna26mmx26mm
C1: 100nF; C_0603_1608Metric
C2: 1yF; C_0603_1608Metric
C3: 470nF; C_0603_1608Metric
CN1: DF12-20DP; DF-12-20DP
D1: LED; LED_0603_1608Metric
R1: 1k; R_0603_1608Metric
U1: RF430CL330H
U2: ublox_SAM-M8Q

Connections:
+3V3: C1.2, C2.1, CN1.2, U1.1, U2.3
GND: C1.1, C2.2, C3.1, CN1.11, CN1.12, CN1.13, CN1.14, CN1.15, CN1.16, CN1.17, CN1.18, CN1.19, CN1.20, D1.1, U1.9, U1.10, U2.1, U2.4, U2.5, U2.6, U2.10, U2.11, U2.15, U2.16, U2.20
GRX: CN1.5, U2.14
GTX: CN1.6, U2.13
NINT: CN1.8, U1.8
NRST: CN1.10, U1.4
unnamed: AE1.1, U1.3
unnamed: AE1.2, U1.2
unnamed: C3.2, U1.14
unnamed: CN1.1, U2.2, U2.17
unnamed: D1.2, R1.2
unnamed: R1.1, U2.7
SCL: CN1.3, U1.11, U2.12
SDA: CN1.4, U1.12, U2.9

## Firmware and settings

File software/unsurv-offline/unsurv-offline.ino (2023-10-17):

// 20 mAh over 1h with 10s sleep 5s active (with BluetoothSerial active)
// 10 mAh over 1h with 25s sleep 5s active
// 6 mAh over 1h with 28s sleep 2s active
// 10 mAh over 1h with 13s sleep 2s active

// new USB power meter
// 13 mah over 1h with gps powerSave 40s sleep 2s active <- good GPS connection?

// TODO validate SD card input data

// attribute  Copyright2 2018 Tlera Corporation for BMA400 Code

#include "BQ25181.h"
#include "BMA400.h"
#include "Wire.h"
#include "LocationUtils.h"
#include "StorageUtils.h"
#include "SurveillanceCamera.h"
#include "NfcUtils.h"
#include "SparkFun_Ublox_Arduino_Library.h"
#include "driver/adc.h"
#include "driver/periph_ctrl.h"
#include "esp_sleep.h"
#include "Arduino_JSON.h"

#define PROXIMITY_ALERT_RADIUS 100 // in m
#define LED 27
#define GPS_WAKEUP_PIN 5

#define MIN_SATS_IN_VIEW 4

#define SEARCH_DURATION 10

#define BITMASK_PIN_25 0x2000000 // needed for ESP32 deepsleep

//BMA400 definitions
#define BMA400_intPin1 25   // interrupt1 pin definitions, wake-up from STANDBY pin
#define BMA400_intPin2 26   // interrupt2 pin definitions, data ready or sleep interrupt

uint8_t Ascale = AFS_2G, SR = SR_50Hz, power_Mode = lowpower_Mode, OSR = osr0, acc_filter = acc_filt2;

float aRes;             // scale resolutions per LSB for the sensor
int16_t accelCount[3];  // Stores the 16-bit signed accelerometer sensor output
int16_t tempCount;      // temperature raw count output
float   temperature;    // Stores the real internal chip temperature in degrees Celsius
float ax, ay, az;       // variables to hold latest sensor data values 
float offset[3];        // accel bias offsets

// Logic flags to keep track of device states
bool BMA400_wake_flag = true;
bool BMA400_sleep_flag = false;
bool InMotion = false;

BMA400 BMA400(BMA400_intPin1, BMA400_intPin2); // instantiate BMA400 class


// battery charging IC
BQ25181 BQ25181(4.2);  // set battery voltage

esp_sleep_wakeup_cause_t wakeup_reason;


boolean enableNfc = true;
boolean sleepOnNoMotion = true;
boolean calibrateBMA400 = false;
// enables a on/off cycle for the whole device specified with "espSleepDuration" and "wakeTime"
boolean savePower = true;

boolean logToSd = true;

int espSleepDuration = 30; // in seconds
int wakeTime = 3; // in seconds

SFE_UBLOX_GPS ubloxGPS;
double latitude, longitude;
long deviceAltitude;
byte SIV;
boolean firstFix = true;

int startTime;

//BluetoothSerial ESP_BT;

LocationUtils locUtils;
StorageUtils storageUtils;


int nearCameraCounter = 0;
SurveillanceCamera nearCameras[MAXNEARCAMERAS];

float distance;
SurveillanceCamera currentCamera;


void setup()
{
  
  Serial.begin(115200);

  //Print the wakeup reason for ESP32
  printWakeupReason();
 
  pinMode(LED, OUTPUT); // power LED
  digitalWrite(LED, HIGH);
  
  // BMA 400 setup
  pinMode(BMA400_intPin1, INPUT);  // define BMA400 wake and sleep interrupt pins as L082 inputs
  pinMode(BMA400_intPin2, INPUT);
  
  BQ25181.setChargingCurrent(2); // 150 mA charging current

  // lower CPU frequency
  setCpuFrequencyMhz(80);

  updateNFC("Natus et libero sed possimus nam. Et illum a voluptas numquam consequatur et cum iure.");
  
  wakeGPS();
  adc_power_on(); 
  delay(100);

  // join I2C bus (I2Cdev library doesn't do this automatically)
  #if I2CDEV_IMPLEMENTATION == I2CDEV_ARDUINO_WIRE
      Wire.begin();
  #elif I2CDEV_IMPLEMENTATION == I2CDEV_BUILTIN_FASTWIRE
      Fastwire::setup(400, true);
  #endif
  
  // setting up MPU 6050 accelerometer
  // initialize device
  // Serial.println("Initializing MPU6050...");
  // accelgyro.initialize();

  // verify connection
  // Serial.println("Testing device connections...");
  // Serial.println(accelgyro.testConnection() ? "MPU6050 connection successful" : "MPU6050 connection failed");

  byte c = BMA400.getChipID();  // Read CHIP_ID register for BMA400
  if(c == 0x90) // check if all I2C sensors with WHO_AM_I have acknowledged
  {
    Serial.println("BMA400 is online..."); Serial.println(" ");

    delay(1000);
    aRes = BMA400.getAres(Ascale);                                       // get sensor resolutions, only need to do this once
    BMA400.resetBMA400();                                                // software reset before initialization
    delay(100);      
    BMA400.selfTestBMA400();                                             // perform sensor self test
    BMA400.resetBMA400();                                                // software reset before initialization
    delay(100);

    

    if (calibrateBMA400) 
    {                                     
      delay(100);                                                         // give some time to read the screen
      BMA400.CompensationBMA400(Ascale, SR, normal_Mode, OSR, acc_filter, offset); // quickly estimate offset bias in normal mode
    }
  }

  BMA400.initBMA400(Ascale, SR, power_Mode, OSR, acc_filter);

  attachInterrupt(BMA400_intPin1, myinthandler1, RISING);  // define wake-up interrupt for INT1 pin output of BMA400
  attachInterrupt(BMA400_intPin2, myinthandler2, RISING);  // define data ready interrupt for INT2 pin output of BMA400 
 
  
  BMA400.getStatus(); // read status of interrupts to clear
  delay(100);
  BMA400.activateNoMotionInterrupt();  

  /*
  accelgyro.setXAccelOffset(1324);
  accelgyro.setYAccelOffset(1300);
  accelgyro.setZAccelOffset(736);
  delay(50);
  accelgyro.setZeroMotionDetectionThreshold(50);
  delay(50);
  // counts no motion events, this counting is slowed 
  // if a low frequency of measurements is used
  accelgyro.setZeroMotionDetectionDuration(50);
  delay(50);
  // interrupts twice, on no motion + on motion
  accelgyro.setIntZeroMotionEnabled(true);
  delay(50);
  // enables low power only accelerator mode
  accelgyro.setWakeCycleEnabled(true);
  delay(50);
  // frequency of measurements
  // 0 = 1.25 Hz, 1 = 2.5 Hz, 2 = 5 Hz, 3 = 10 Hz
  // this does seem to slow counting of motion events used for DetectionDuration above
  accelgyro.setWakeFrequency(2);
  delay(50);
  */

  // setting up ublox GPS

  if (ubloxGPS.begin() == false) //Connect to the Ublox module using Wire port
  {
    Serial.println(F("Ublox GPS not detected at default I2C address. Location services NOT AVAILABLE."));
    Serial.println(F("Ublox GPS not detected at default I2C address. Location services NOT AVAILABLE."));
    Serial.println(F("Ublox GPS not detected at default I2C address. Location services NOT AVAILABLE."));
    
  }

  ubloxGPS.setI2COutput(COM_TYPE_UBX); //Set the I2C port to output UBX only (turn off NMEA noise)
  ubloxGPS.powerSaveMode(true);
  ubloxGPS.saveConfiguration(); //Save the current settings to flash and BBR

  startTime = millis();

  Serial.println("GPS power save: " + String(ubloxGPS.getPowerSaveMode()));

  Serial.println("Initialization complete...");

  String jsonString;
  JSONVar nfcData;
  nfcData["batt"] = 100;
  JSONVar contactArray;
  contactArray = storageUtils.getContacts(2);
          
  nfcData["c"] = contactArray;
  jsonString = "{\"b\":100,\"c\":[";

  for (int i = 0; i < contactArray.length(); i++)
  {

    String con = JSON.stringify(contactArray[i]);
    con.replace("\\", "");
    con.remove(0, 1);
    con.remove(con.length() - 1, 1);
    Serial.println(con);
    jsonString.concat(con);
    
    if (contactArray.length() - 1 - i != 0)
    {
      jsonString.concat(",");  
    }
    
  }

  jsonString.concat("]}");
  Serial.println(jsonString);
  
     
  // updateNFC(jsonString);
  
  updateNFC("Natus et libero sed possimus nam. Et illum a voluptas numquam consequatur et cum iure. Voluptas dolorem aspernatur est est neque ut fugit quisquam. Et ut placeat libero est voluptatem necessitatibus eum. ur et cum iure. Voluptas dolorem aspernatur est est neque ut fugit quisquam.  ur et cum iure. Voluptas dolorem aspernatur est est neque ut fugit quisquam.  ur et cum iure. Voluptas dolorem aspernatur est est neque ut fugit quisquam.  ur et cum iure. Voluptas dolorem aspernatur est est neque ut fugit quisquam.");
  // updateNFC("loren ipsum asdasdasd");
}

void loop()
{

  /* BMA400 sleep/wake detect*/
  if(BMA400_wake_flag)
  {
    BMA400_wake_flag = false; // clear the wake flag
    InMotion = true;          // set motion state latch
    BMA400.activateNoMotionInterrupt();  
    attachInterrupt(BMA400_intPin2, myinthandler2, RISING);  // attach no-motion interrupt for INT2 pin output of BMA400 

  }

  if(BMA400_sleep_flag)
  {
    BMA400_sleep_flag = false;            // clear the sleep flag
    InMotion = false;                     // set motion state latch
    detachInterrupt(BMA400_intPin2);       // Detach the BMA400 "Go to sleep" interrupt so it doesn't spuriously wake the STM32L4
    BMA400.deactivateNoMotionInterrupt(); // disable no-motion interrupt to save power
   
    if (sleepOnNoMotion)
    {
      startDeepSleep(0); 
    }
   
  }/* end of sleep/wake detect */
  
  
  if (millis() < startTime + (wakeTime * 1000) || !savePower || firstFix)
  {
    //The GPS module only responds when a new position is available          
    latitude = (double) ubloxGPS.getLatitude() / 10000000;
    longitude = (double) ubloxGPS.getLongitude() / 10000000;
    deviceAltitude = ubloxGPS.getAltitude(); // in mm

    // satellites in view
    SIV = ubloxGPS.getSIV();

    Serial.println("-------------------------------");
    Serial.println("SIV: " + String(SIV));
    //ESP_BT.println();

    // creating a JSON to log to SD and later transmit via nfc
    // need to keep data as short as possible, we can only transmit 3kb via the RF 430 NFC chip
    JSONVar nfcData;

    
    if (SIV < MIN_SATS_IN_VIEW) // less than 3 satellites in view, scan for SEARCH_DURATION in seconds
    {
      
      long searchStart = millis();
      ubloxGPS.powerSaveMode(false);
      delay(100);
      Serial.println("GPS power save: " + String(ubloxGPS.getPowerSaveMode()));
      firstFix = true;

      Serial.println(searchStart + millis());
      Serial.println(searchStart + (SEARCH_DURATION * 1000));
      
      while ((millis() < searchStart + (SEARCH_DURATION * 1000)) && SIV < MIN_SATS_IN_VIEW)
      {
        SIV = ubloxGPS.getSIV();
        Serial.println("scanning for GPS satellites: SIV " + String(SIV));
        // change firstFix state to true here?
        delay(1000);      
      }
    }
    else // more than MIN_SATS_IN_VIEW
    { 
      printGpsData();
      short int radius = 100;

      if (firstFix)
      {
        Serial.println("first satellite fix ... querying SD card for data");
        // switch on power save after sats have been found
        ubloxGPS.powerSaveMode(true);
        delay(100);

        
        startTime = millis();
        nearCameraCounter = storageUtils.getCamerasFromSD(latitude, longitude, radius, nearCameras);

        if (nearCameraCounter == -1) {
          startDeepSleep(0);
        }
        
        while (nearCameraCounter == -2) // returns -2 if too many cameras are in current radius
        {
          radius = radius / 2;
          Serial.println(String(radius));
          nearCameraCounter = storageUtils.getCamerasFromSD(latitude, longitude, radius, nearCameras);
        }
  
        firstFix = false;
      }

      JSONVar current_location;

      current_location["lat"] = latitude;
      current_location["lon"] = longitude;
      // current_location["alt"] = deviceAltitude;
      current_location["SIV"] = SIV;
      current_location["t"] = getTimeString();
  
      // nfcData += " Lat: " + String(latitude, 5) + " Lon: " + String(longitude, 5) + " Alt: " + String(deviceAltitude) + " mm -- SIV: " + String(SIV) + "\n";
      
      nfcData["loc"] = current_location;
     
      // check distance for all debug cameras and print id + distance

      
      for (int i = 0; i < nearCameraCounter; i++) 
      {
        currentCamera = nearCameras[i];
  
        distance = locUtils.getDistanceToCamera(latitude, longitude, currentCamera.latitude, currentCamera.longitude);
        
        // nfcData += "Id: " + String(currentCamera.id) + " Distance: " + String(distance, 3) + '\n';
        
        
        delay(50);

         if (distance < PROXIMITY_ALERT_RADIUS)
        {
          Serial.println("object in close proximity");
          JSONVar contact;

          // contact["distance"] = distance;
          Serial.println(String(currentCamera.latitude, 5));
          Serial.println(String(currentCamera.longitude, 5));
          Serial.println(String(currentCamera.cameraType));
          Serial.println(String(currentCamera.id));
          
          nfcData["ids"][i] = String(currentCamera.id);
          
        }
  
      }
    }

    String jsonString = JSON.stringify(nfcData);
    // Serial.println(jsonString);

    if (nfcData["ids"].length() > 0) {
      Serial.println("MORE THAN ONE CAMERA IS IN YOUR AREA");
      Serial.println(jsonString);
      storageUtils.logToSd("contacts.txt", jsonString);
      
    }

    if (enableNfc)
    {
      nfcData["batt"] = estimateBatteryLevel();

      JSONVar contactArray = storageUtils.getContacts(10);    
      nfcData["c"] = contactArray;
      // Serial.println(JSON.stringify(nfcData));
      jsonString = JSON.stringify(nfcData);
      
      updateNFC(jsonString);
    }

    
    if (SIV >= MIN_SATS_IN_VIEW && logToSd)
    {
      // logging to SD card
      storageUtils.logToSd("logFile.txt", String(latitude, 6) + "," + String(longitude, 6) + "," + String(deviceAltitude) + "," + String(SIV) + "," + getDateTimeString());
    }
    
    

    delay(100);

  } 
  else // not in active state
  {
    if (SIV < MIN_SATS_IN_VIEW)
    {
      // increase sleep time here for each search duration without success
      // no satellites in view, sleep for 2 mins and try again
      Serial.println("No Satellites in view, sleeping for 2 minutes.");
      // todo increase sleep time here depending on number of unsuccessful searches for GPS signal beforehand
      startDeepSleep(120);
    }
    else // regular active/sleep cycle while GPS satellites in view
    {
      startDeepSleep(espSleepDuration);
    }
  }
}

void myinthandler1()
{
  BMA400_wake_flag = true; 
  Serial.println("** BMA400 is awake! **");
}


void myinthandler2()
{
  BMA400_sleep_flag = true;
  Serial.println("** BMA400 is asleep! **");
}


void startDeepSleep(int timer) {

  if (timer != 0)
  {
    Serial.println("Setup ESP32 to sleep for " + String(timer) +" seconds");
    //ESP_BT.println("Setup ESP32 to sleep for " + String(espSleepDuration) +" seconds");

    delay(50);
    //Go to sleep now
    pinMode(LED, OUTPUT); // power LED
    digitalWrite(LED, LOW);
    
    
    esp_sleep_enable_timer_wakeup(timer * 1000000); // ys conversion
    delay(100);
    
    // if timer is longer than 45 s switch gps completely off
    if (timer > 45 * 1000000)
    {
      ubloxGPS.powerOff(0);
    }
    
    delay(100);
    // accelgyro.setZeroMotionDetectionDuration(10);
    adc_power_off();

    esp_sleep_pd_config(ESP_PD_DOMAIN_RTC_PERIPH, ESP_PD_OPTION_OFF);
    esp_sleep_pd_config(ESP_PD_DOMAIN_RTC_SLOW_MEM, ESP_PD_OPTION_OFF);
    esp_sleep_pd_config(ESP_PD_DOMAIN_RTC_FAST_MEM, ESP_PD_OPTION_OFF);
    
    delay(100);
    esp_deep_sleep_start();
  }
  else
  {
    // wire mpu6050 int pin to GPIO25
    // esp_sleep_enable_ext0_wakeup(GPIO_NUM_25, 1); //1 = High, 0 = Low < This keeps gpio stuff powered, no bueno
     
    esp_sleep_enable_ext1_wakeup(BITMASK_PIN_25, ESP_EXT1_WAKEUP_ANY_HIGH);
  
    // lower sensitivity to allow low frequency wakeups
    // accelgyro.setZeroMotionDetectionDuration(10);
    
    //Go to sleep now
    Serial.println("Going to sleep now");
    pinMode(LED, OUTPUT); // power LED
    digitalWrite(LED, LOW);
  
    delay(100);
    ubloxGPS.powerOff(0); // 0 = indefinetly
    Serial.println("shutting down ublox module");
    delay(100);
    adc_power_off();  
    delay(100);
    esp_deep_sleep_start();
  }
}

void printWakeupReason(){

  wakeup_reason = esp_sleep_get_wakeup_cause();

  switch(wakeup_reason)
  {
    case ESP_SLEEP_WAKEUP_EXT0 : Serial.println("Wakeup caused by external signal using RTC_IO"); break;
    case ESP_SLEEP_WAKEUP_EXT1 : Serial.println("Wakeup caused by external signal using RTC_CNTL"); break;
    case ESP_SLEEP_WAKEUP_TIMER : Serial.println("Wakeup caused by timer"); break;
    case ESP_SLEEP_WAKEUP_TOUCHPAD : Serial.println("Wakeup caused by touchpad"); break;
    case ESP_SLEEP_WAKEUP_ULP : Serial.println("Wakeup caused by ULP program"); break;
    default : Serial.printf("Wakeup was not caused by deep sleep: %d\n",wakeup_reason); break;
  }
}

void printAccellData()
{
  Serial.print("a/g:\t");
  Serial.print(ax); Serial.print("\t");
  Serial.print(ay); Serial.print("\t");
  Serial.println(az);
}

void printGpsData()
{

  Serial.println(getDateTimeString());

  Serial.print(F(" SIV: "));
  Serial.print(SIV);
  //ESP_BT.print(F(" SIV: "));
  //ESP_BT.print(SIV);
  
  Serial.println();
  Serial.print(F("Lat: "));
  Serial.print(String(latitude, 5));
  //ESP_BT.print(F("Lat: "));
  //ESP_BT.print(String(latitude, 5));

  Serial.print(F(" Lon: "));
  Serial.print(String(longitude, 5));
  //ESP_BT.print(F(" Lon: "));
  //ESP_BT.print(String(longitude, 5));

  Serial.print(F(" Alt: "));
  Serial.print(deviceAltitude);
  Serial.print(F(" (mm)"));
  //ESP_BT.print(F(" Alt: "));
  //ESP_BT.print(altitude);

  Serial.println();
  //ESP_BT.println();

}

void wakeGPS() 
{
  pinMode(GPS_WAKEUP_PIN , OUTPUT);
  delay(100);
  digitalWrite(GPS_WAKEUP_PIN , LOW);
  Serial.println("WAKING UP GPS VIA EXINT PIN");
  delay(100);
  digitalWrite(GPS_WAKEUP_PIN , HIGH);
  delay(100);
  digitalWrite(GPS_WAKEUP_PIN , LOW);
  delay(100);
  pinMode(GPS_WAKEUP_PIN , INPUT);

}

String getDateTimeString()
{
  // THIS IS UGLY
  if (ubloxGPS.getDateValid() && ubloxGPS.getTimeValid())
  {
    return String(ubloxGPS.getYear()) + "-" + String(ubloxGPS.getMonth()) + "-" + String(ubloxGPS.getDay()) 
    + " " + String(ubloxGPS.getHour()) + ":" + String(ubloxGPS.getMinute()) + ":" + String(ubloxGPS.getSecond());
  }
  else 
  {
    return "no valid data";
  }
}

String getTimeString()
{
  // THIS IS UGLY
  if (ubloxGPS.getDateValid() && ubloxGPS.getTimeValid())
  {
    return String(ubloxGPS.getHour()) + ":" + String(ubloxGPS.getMinute()) + ":" + String(ubloxGPS.getSecond());
  }
  else 
  {
    return "no valid data";
  }
}

int estimateBatteryLevel()
{
  float voltage = analogRead(35) * 7.29 / 4096.0;
  int percentage = 100;
  float maxChargeVoltage = 4.18;

  
  // lipo discharges nonlinear
  Serial.println("Voltage: " + String(voltage));
  // from 100 to 80 %
  if (voltage > 4.02)
  {
     percentage -= ((maxChargeVoltage - voltage) / 0.12f) * 10.0f;
  }
  else if (voltage <= 4.02 && voltage >= 3.87) // 80 - 60 %
  {
    percentage = 80;
    percentage -= ((4.02 - voltage) / 0.07f) * 10.0f;
  }
  else if (voltage <= 3.87 && voltage >= 3.64) // 60 - 10 %
  {
    percentage = 60;
    percentage -= (int) ((3.87 - voltage) / 0.04f) * 10.0f;
  }
  else
  {
    percentage = 0;
  }

  Serial.println("Percentage: " + String(percentage));

  return percentage;
}

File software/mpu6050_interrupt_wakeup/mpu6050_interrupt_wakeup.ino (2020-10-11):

// I2C device class (I2Cdev) demonstration Arduino sketch for MPU6050 class
// 10/7/2011 by Jeff Rowberg <jeff@rowberg.net>
// Updates should (hopefully) always be available at https://github.com/jrowberg/i2cdevlib
//
// Changelog:
//      2013-05-08 - added multiple output formats
//                 - added seamless Fastwire support
//      2011-10-07 - initial release

/* ============================================
I2Cdev device library code is placed under the MIT license
Copyright (c) 2011 Jeff Rowberg
Permission is hereby granted, free of charge, to any person obtaining a copy
of this software and associated documentation files (the "Software"), to deal
in the Software without restriction, including without limitation the rights
to use, copy, modify, merge, publish, distribute, sublicense, and/or sell
copies of the Software, and to permit persons to whom the Software is
furnished to do so, subject to the following conditions:
The above copyright notice and this permission notice shall be included in
all copies or substantial portions of the Software.
THE SOFTWARE IS PROVIDED "AS IS", WITHOUT WARRANTY OF ANY KIND, EXPRESS OR
IMPLIED, INCLUDING BUT NOT LIMITED TO THE WARRANTIES OF MERCHANTABILITY,
FITNESS FOR A PARTICULAR PURPOSE AND NONINFRINGEMENT. IN NO EVENT SHALL THE
AUTHORS OR COPYRIGHT HOLDERS BE LIABLE FOR ANY CLAIM, DAMAGES OR OTHER
LIABILITY, WHETHER IN AN ACTION OF CONTRACT, TORT OR OTHERWISE, ARISING FROM,
OUT OF OR IN CONNECTION WITH THE SOFTWARE OR THE USE OR OTHER DEALINGS IN
THE SOFTWARE.
===============================================
*/

// I2Cdev and MPU6050 must be installed as libraries, or else the .cpp/.h files
// for both classes must be in the include path of your project
// #include "I2Cdev.h"
#include "MPU6050.h"

// Arduino Wire library is required if I2Cdev I2CDEV_ARDUINO_WIRE implementation
// is used in I2Cdev.h
#if I2CDEV_IMPLEMENTATION == I2CDEV_ARDUINO_WIRE
    #include "Wire.h"
#endif

// class default I2C address is 0x68
// specific I2C addresses may be passed as a parameter here
// AD0 low = 0x68 (default for InvenSense evaluation board)
// AD0 high = 0x69
// MPU6050 accelgyro;
MPU6050 accelgyro(0x69); // <-- use for AD0 high

int16_t oldax, olday, oldaz;
int16_t oldgx, oldgy, oldgz;

int16_t ax, ay, az;
int16_t gx, gy, gz;


// uncomment "OUTPUT_READABLE_ACCELGYRO" if you want to see a tab-separated
// list of the accel X/Y/Z and then gyro X/Y/Z values in decimal. Easy to read,
// not so easy to parse, and slow(er) over UART.
#define OUTPUT_READABLE_ACCELGYRO

// uncomment "OUTPUT_BINARY_ACCELGYRO" to send all 6 axes of data as 16-bit
// binary, one right after the other. This is very fast (as fast as possible
// without compression or data loss), and easy to parse, but impossible to read
// for a human.
//#define OUTPUT_BINARY_ACCELGYRO


#define LED_PIN 26
bool blinkState = false;

/*
Method to print the reason by which ESP32
has been awaken from sleep
*/
void print_wakeup_reason(){
  esp_sleep_wakeup_cause_t wakeup_reason;

  wakeup_reason = esp_sleep_get_wakeup_cause();

  switch(wakeup_reason)
  {
    case ESP_SLEEP_WAKEUP_EXT0 : Serial.println("Wakeup caused by external signal using RTC_IO"); break;
    case ESP_SLEEP_WAKEUP_EXT1 : Serial.println("Wakeup caused by external signal using RTC_CNTL"); break;
    case ESP_SLEEP_WAKEUP_TIMER : Serial.println("Wakeup caused by timer"); break;
    case ESP_SLEEP_WAKEUP_TOUCHPAD : Serial.println("Wakeup caused by touchpad"); break;
    case ESP_SLEEP_WAKEUP_ULP : Serial.println("Wakeup caused by ULP program"); break;
    default : Serial.printf("Wakeup was not caused by deep sleep: %d\n",wakeup_reason); break;
  }
}

void setup() {

    // initialize serial communication
    // (38400 chosen because it works as well at 8MHz as it does at 16MHz, but
    // it's really up to you depending on your project)
    Serial.begin(9600);

    //Print the wakeup reason for ESP32
    print_wakeup_reason();
    
    // join I2C bus (I2Cdev library doesn't do this automatically)
    #if I2CDEV_IMPLEMENTATION == I2CDEV_ARDUINO_WIRE
        Wire.begin();
    #elif I2CDEV_IMPLEMENTATION == I2CDEV_BUILTIN_FASTWIRE
        Fastwire::setup(400, true);
    #endif

    accelgyro.reset();
    delay(500);

    // initialize device
    Serial.println("Initializing MPU6050...");
    accelgyro.initialize();

    // verify connection
    Serial.println("Testing device connections...");
    Serial.println(accelgyro.testConnection() ? "MPU6050 connection successful" : "MPU6050 connection failed");
    
    delay(100);
    accelgyro.setZeroMotionDetectionThreshold(20);
    delay(100);
    // counts no motion events, this counting is slowed 
    // because a low frequency of measurements is used
    accelgyro.setZeroMotionDetectionDuration(5);
    delay(100);
    // interrupts twice, on no motion + on motion
    accelgyro.setIntZeroMotionEnabled(true);
    delay(100);
    // enables low power only accelerator mode
    accelgyro.setWakeCycleEnabled(true);
    delay(100);
    // frequency of measurements
    // 0 = 1.25 Hz, 1 = 2.5 Hz, 2 = 5 Hz, 3 = 10 Hz
    // this does seem to slow counting of motion events used for DetectionDuration above
    accelgyro.setWakeFrequency(3);

    // initialize with values that wont be equal to a measurement
    oldax = 0; 
    olday = 0;
    oldaz = 0;

    // use the code below to change accel/gyro offset values
    /*
    Serial.println("Updating internal sensor offsets...");
    // -76  -2359 1688  0 0 0
    Serial.print(accelgyro.getXAccelOffset()); Serial.print("\t"); // -76
    Serial.print(accelgyro.getYAccelOffset()); Serial.print("\t"); // -2359
    Serial.print(accelgyro.getZAccelOffset()); Serial.print("\t"); // 1688
    Serial.print(accelgyro.getXGyroOffset()); Serial.print("\t"); // 0
    Serial.print(accelgyro.getYGyroOffset()); Serial.print("\t"); // 0
    Serial.print(accelgyro.getZGyroOffset()); Serial.print("\t"); // 0
    Serial.print("\n");
    accelgyro.setXGyroOffset(220);
    accelgyro.setYGyroOffset(76);
    accelgyro.setZGyroOffset(-85);
    Serial.print(accelgyro.getXAccelOffset()); Serial.print("\t"); // -76
    Serial.print(accelgyro.getYAccelOffset()); Serial.print("\t"); // -2359
    Serial.print(accelgyro.getZAccelOffset()); Serial.print("\t"); // 1688
    Serial.print(accelgyro.getXGyroOffset()); Serial.print("\t"); // 0
    Serial.print(accelgyro.getYGyroOffset()); Serial.print("\t"); // 0
    Serial.print(accelgyro.getZGyroOffset()); Serial.print("\t"); // 0
    Serial.print("\n");
    */

    // configure Arduino LED pin for output
    // pinMode(LED_PIN, OUTPUT);
}
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

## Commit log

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2020-04-03 changed from EasyEDA to KiCad
    [unsurv_offline_pcb.kicad_pcb, unsurv_offline_pcb.sch]
2020-04-04 Revert "changed from EasyEDA to KiCad"
    This reverts commit 82435eca3ce34d20457a26c89086bcd967547cae.
    [unsurv_offline_pcb.kicad_pcb, unsurv_offline_pcb.sch]
2020-04-04 changed from EasyEDA to KiCad
    this time with less files
    [unsurv_offline_pcb.kicad_pcb, unsurv_offline_pcb.sch]
2020-04-04 organizing files
    [unsurv_offline_pcb.kicad_pcb]
2020-04-04 added schematic for addon board
    [NFC-GPS.kicad_pcb, NFC-GPS.sch, unsurv_offline_pcb.kicad_pcb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]
2020-04-05 added DF40C-20 footprints
    [unsurv_offline_pcb.kicad_pcb]
2020-04-06 added NFC-GPS pcb
    [NFC-GPS.kicad_pcb, NFC-GPS.sch]
2020-04-08 added power switch for GPS
    [unsurv_offline_pcb.kicad_pcb, unsurv_offline_pcb.sch]
2020-05-20 started basic case
    [case.FCStd]
2020-06-12 simplified power input
    [unsurv_offline_pcb.sch]
2020-06-13 reworked data retrieval from SD
    [get_data_from_SD.ino]
2020-06-27 reducing pcb size
    [unsurv_offline_pcb.kicad_pcb, unsurv_offline_pcb.sch]
2020-06-27 placing components on small pcb
    [unsurv_offline_pcb.kicad_pcb]
2020-06-29 created small pcb with 4 layers
    [unsurv_offline_2layer_pcb.kicad_pcb, unsurv_offline_pcb.kicad_pcb, unsurv_offline_pcb.sch]
2020-07-04 added addressable LED
    [unsurv_offline_2layer_pcb.kicad_pcb, unsurv_offline_pcb.kicad_pcb, unsurv_offline_pcb.sch]
2020-07-10 pcb work
    [unsurv_offline_pcb.kicad_pcb, unsurv_offline_pcb.sch]
2020-07-12 added testpoints
    [unsurv_offline_pcb.kicad_pcb, unsurv_offline_pcb.sch]
2020-07-12 added battery monitoring circuit
    [unsurv_offline_pcb.kicad_pcb, unsurv_offline_pcb.sch]
2020-07-15 fixed microvias
    [unsurv_offline_pcb.kicad_pcb]
2020-07-18 added pps LED + fixed F.Mask
    [unsurv_offline_pcb.kicad_pcb, unsurv_offline_pcb.sch]
2020-07-20 3.5 cm x 5 cm prototype
    [unsurv_offline_pcb.kicad_pcb, unsurv_offline_pcb.sch]
2020-07-21 no conn to pin 12, defines memory voltage at boot
    [unsurv_offline_pcb.kicad_pcb, unsurv_offline_pcb.sch]
2020-08-09 fixed NCP59800 footprint
    [unsurv_offline_pcb.kicad_pcb, unsurv_offline_pcb.sch]
2020-08-20 charging circuit cleanup + new GPS
    [unsurv_offline_pcb.kicad_pcb, unsurv_offline_pcb.sch]
2020-08-23 improved routing + less vias
    [unsurv_offline_pcb.kicad_pcb, unsurv_offline_pcb.sch]
2020-08-30 USB power/ lipo charging part 27
    [unsurv_offline_pcb.kicad_pcb, unsurv_offline_pcb.sch]
2020-08-30 USB power/ lipo charging part 28
    [unsurv_offline_pcb.kicad_pcb]
2020-09-01 added 3x2 pads for pogo pins
    [unsurv_offline_pcb.kicad_pcb, unsurv_offline_pcb.sch]
2020-09-21 added RF430CL330H to schematic
    [unsurv_offline_pcb.sch]
2020-09-22 added RF430CL330H to pcb
    [unsurv_offline_pcb.kicad_pcb, unsurv_offline_pcb.sch]
2020-09-23 bottom case
    [case.FCStd, case_bottom.FCStd, case_bottom.stl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]
2020-09-23 top case
    [case_top.FCStd, case_top.stl]
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2020-09-27 fixed microSD cutout
    [case_top.FCStd]
2020-09-27 top case 3D printing file
    [case_top.stl]
2020-09-28 started smaller pcb version
    [small_pcb.kicad_pcb, unsurv_offline_pcb.sch]
2020-10-02 reduced pcb size
    [small_pcb.kicad_pcb, small_pcb.sch]
2020-10-07 finalized smaller pcb
    [small_pcb.kicad_pcb, small_pcb.sch, unsurv_offline_pcb.kicad_pcb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]
2020-10-11 added motion activation + code refactoring
    [small_pcb.kicad_pcb, small_pcb.sch]
2020-10-19 added small case
    [case_bottom.FCStd, case_bottom.stl, case_top.FCStd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]
2020-10-21 fixed no motion sleep
    [unsurv-offline.ino]
2020-10-23 lowered power consumption in deep sleep
    [small_pcb.kicad_pcb, small_pcb.sch]
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2020-11-07 fixed power consumption while savePower is active
    [unsurv-offline.ino]
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2020-11-19 better clips for case
    [case_bottom.FCStd, case_bottom.stl, case_top.FCStd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]
2020-11-20 changed order of charge LED
    [small_pcb.sch]
2020-11-20 changedcase edges
    [case_bottom.FCStd, case_top_rebuild.FCStd]
2020-11-30 fixed datatype of OSM camera IDs
    [StorageUtils.cpp, unsurv-offline.ino]
2020-12-04 reworked case
    [case_bottom.stl, case_top.stl, case_top_rebuild.FCStd]
2020-12-05 small improvements to case top
    [case_top.stl, case_top_rebuild.FCStd]
2020-12-08 non "short record" ndef type
    up to 3000 bytes via NFC PogChamp
    [NfcUtils.h, unsurv-offline.ino]
2020-12-09 fixed ndef length fields
    [NfcUtils.h, unsurv-offline.ino]
2020-12-22 demo changes
    [case_bottom.stl, case_top.stl]
2021-03-13 fixed KiCad library issues
    [small_pcb.sch]
2021-05-14 updated 3D files + exported schematic
    [case_top.FCStd, screw_case_bottom.FCStd, screw_case_botttom.stl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]
2021-06-19 prep for rework
    [small_pcb.sch]
2021-06-30 added ESP D4 variant
    [d4_small_pcb.kicad_pcb, d4_small_pcb.sch, small_pcb.kicad_pcb]
2021-07-15 case reworks
    [d4_case_bottom.FCStd, d4_case_bottom.stl, d4_case_top .FCStd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]
2021-07-28 improved image edges
    [d4_case_bottom.FCStd, d4_case_top .FCStd, d4_case_top.stl]
2021-08-05 d4 case updates
    [d4_case_bottom.FCStd, d4_case_bottom.stl, d4_case_top .FCStd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]
2021-08-11 small updates to PCB and case
    [d4_case_bottom.FCStd, d4_case_top .FCStd, d4_case_top.stl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]
2021-09-16 small improvements to the case
    [d4_case_bottom.FCStd, d4_case_bottom.stl, d4_case_bottom_test.FCStd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]
2021-09-16 restructuring folders
    [NFC-GPS.kicad_pcb, NFC-GPS.sch, case_bottom.FCStd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]
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2021-11-15 added new example + images
    [d4_case_top .FCStd, d4_case_top.stl]
2022-01-14 added expansion and JST
    [d4_small_pcb.kicad_pcb, d4_small_pcb.kicad_sch]
2022-01-14 changed voltage divider routing
    [d4_small_pcb.kicad_pcb]
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2022-02-18 added new 3D case + PCB rework
    [d4_case_bottom_collar_mount-Body.stl, d4_case_bottom_collar_mount.FCStd, d4_small_pcb.kicad_pcb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]
2022-06-06 pre rework
    [d4_small_pcb.kicad_sch]
2022-07-13 PCB redesign
    [d4_small_pcb.kicad_pcb]
2022-09-10 moving passives around BQ25181
    [d4_small_pcb.kicad_pcb, d4_small_pcb.kicad_sch]
2022-12-10 update RF430 package to VQFN
    [d4_small_pcb.kicad_pcb, d4_small_pcb.kicad_sch]
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2023-01-15 BQ25180 redesign
    [d4_small_pcb.kicad_pcb, d4_small_pcb.kicad_sch]
2023-01-15 lower clearance for GND fills
    [d4_small_pcb.kicad_pcb]
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2023-06-20 remove hand soldering footprints
    [d4_small_pcb.kicad_pcb, d4_small_pcb.kicad_sch]
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2024-11-21 update text + add panel for production
    [NFC-GPS.kicad_pcb, NFC-GPS.sch, d4_small_pcb.kicad_pcb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]
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2024-11-22 update BMA400 +BQ25180 footprints
    [d4_small_pcb.kicad_pcb, d4_small_pcb.kicad_sch]
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2024-11-25 repair project + update 3D model path for KiCad 8
    [d4_small_pcb.kicad_pcb, d4_small_pcb.kicad_sch]
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
